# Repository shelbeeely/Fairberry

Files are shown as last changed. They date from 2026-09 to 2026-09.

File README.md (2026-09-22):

# Fairberry (e-ink fork)

This is a personal fork of [Dakkaron/Fairberry](https://github.com/Dakkaron/Fairberry), which adds a detachable BlackBerry Q10 keyboard to phones, physically clamped on and wired over USB. If you want that original phone-focused project, go there instead — this fork has moved away from it.

**The direction here now: a standalone, battery-powered BlackBerry-style device -- Q10 keyboard, a five-way trackball, a mic and speaker, microSD storage -- that pairs *wirelessly* with the [Xteink X4](https://www.xteink.com/products/xteink-x4) (or any BLE HID host) instead of physically attaching to it.** No separate battery / host-powered-only was the original project's whole philosophy; this fork has deliberately dropped that in favor of its own LiPo battery and its own enclosure, built primarily for e-ink devices running the [Free Ink SDK](https://freeink.org/) but not exclusive to them -- anything that speaks BLE HID keyboard is a valid target.

See [Hardware_Standalone_Smart_Keyboard.md](Documentation/Hardware_Standalone_Smart_Keyboard.md) for the current primary build. Two earlier, simpler stages are still in the repo and still valid if you want something less involved:
1. [Hardware_Fairberry_Mainboard.md](Documentation/Hardware_Fairberry_Mainboard.md) -- the original USB/BLE keyboard-only mainboard.
2. [Hardware_ESP32_Trackball_Mainboard.md](Documentation/Hardware_ESP32_Trackball_Mainboard.md) -- adds the trackball, still host-powered, classic ESP32.

The standalone smart keyboard supersedes both for pairing with the X4 specifically, but they're simpler builds if you don't want the battery/mic/speaker/SD/WiFi scope.

## Writer deck: four components, one repo

The keyboard alone is one half of the picture. Combined with an X4 running a FreeInk-SDK writer app, this becomes a full distraction-free writing device -- a "writer deck," in the vein of a Freewrite or AlphaSmart, built from this project's own parts. Four separate-but-interlinked pieces, all in this repo:

| Component | Directory | What it is |
|---|---|---|
| Keyboard firmware | [`BBQ10/`](BBQ10) | The physical keyboard + trackball + voice typing, BLE HID |
| X4 firmware | [`X4Firmware/`](X4Firmware) | The writer app (library + editor screens) running on the X4 |
| Hardware | [`KiCad/`](KiCad), [`Case/`](Case) | PCB design, 3D-printable case |
| Web GUI | [`WebGUI/`](WebGUI) | The keyboard-hosted local browser dashboard (implementation lives in `BBQ10/web_server.h`) |

Start with [Hardware_X4_Writer_Deck.md](Documentation/Hardware_X4_Writer_Deck.md) for how the pieces fit together -- it's also the most honestly unproven part of this repo (see its Status section: I read FreeInk SDK's docs site, but never had the actual SDK source or hardware in front of me to compile/test against, unlike the keyboard firmware).

## Status / known limitation

Good news on the software side: FreeInk SDK has a purpose-built BLE keyboard host — [`BleKeyboardHost`](https://freeink.org/docs/lib-ble) (the `lib-ble` library). Per its docs, it's a real BLE HID **host** (central role) that explicitly supports "keyboards, page turners, remote buttons and similar devices that expose the HID service" — not just page-turner remotes as I originally assumed here. It works on both ESP32-C3 and ESP32-S3 (BLE only, no Bluetooth Classic), which covers the plain X4 (C3) as well as the X4 Classic/Pro (S3). Pairing defaults to "Just Works" (no passkey needed), which is what a keyboard-only peripheral like Fairberry's `BOARD_TYPE ESP32` needs.

The catch: it's an **opt-in capability**, gated behind the `FREEINK_CAP_BLE_HID_HOST` build flag (off by default) plus adding the NimBLE stack as a dependency. So the real question isn't "does the ecosystem support external keyboards" (it does) — it's "does the specific firmware image flashed on your X4 have that flag turned on." Stock/vendor Xteink firmware almost certainly doesn't.

Checked directly against [freeink-sdk's `platformio.sample.ini`](https://github.com/Free-Ink/freeink-sdk/blob/main/platformio.sample.ini): the stock `[env:xteink_x4]` build env is just

```ini
[env:xteink_x4]
extends = base
board = esp32-c3-devkitm-1
build_flags =
  ${base.build_flags}
  -DFREEINK_DEVICE_X4=1
```

— no BLE HID host flag. Building a FreeInk-SDK firmware for the X4 that can actually pair with a Fairberry keyboard means adding, at minimum:

```ini
build_flags =
  ${base.build_flags}
  -DFREEINK_DEVICE_X4=1
  -DFREEINK_CAP_BLE_HID_HOST=1
lib_deps =
  ${base.lib_deps}
  h2zero/NimBLE-Arduino@^2.3.8
```

to your own build, then flashing that instead of whatever firmware is on the device now.

I have **not yet confirmed** this end-to-end against a physical X4 — that's the next step. I also haven't found documented USB HID host support in FreeInk SDK for any target, so the USB-attached Fairberry board types (`FAIRBERRY_V0_3_0`, `ARDUINO`) are more speculative than the BLE path right now; BLE (`BOARD_TYPE ESP32`) is the one with an actual matching host-side API to target.

## What can you expect?

Everything from the upstream project still applies at the electronics level: same BBQ10 keyboard, same mainboard, same firmware, same key combos (cursor mode, sticky modifiers, dead keys, backlight controls — see [UX_Shortcuts_and_Apps.md](Documentation/UX_Shortcuts_and_Apps.md)). What's changing here is the case/mount and the target device.

Demo video of the original phone version: Demo video showing the functionality of the Fairberry keyboard (https://www.youtube.com/watch?v=iDb8_ld9gOQ)

## How to build it?

**Standalone smart keyboard (primary build)**: `BOARD_TYPE FAIRBERRY_ESP32S3_SMART` on an ESP32-S3. See [Hardware_Standalone_Smart_Keyboard.md](Documentation/Hardware_Standalone_Smart_Keyboard.md) for the pin plan, BOM (mic, speaker, microSD, LiPo + charger), firmware, and key combo table. Opt-in flags in `configuration.h`: `TRACKBALL_ENABLED`, `AUDIO_ENABLED` (local recording/playback, fully offline), `WIFI_TRANSCRIPTION_ENABLED` (batch-syncs recordings to the OpenAI Whisper API), `TRANSFER_MODE_ENABLED` (local no-cloud web dashboard for browsing/downloading notes over LAN), `VOICE_TYPING_ENABLED` (immediate dictate -> hear it read back via TTS to verify -> Enter to send, like a phone's voice-to-text keyboard). The last three need `BBQ10/secrets.h` -- copy `secrets.h.example`. No enclosure design yet -- see that doc's Enclosure section for why. **None of this is validated against real hardware.**

**Simpler builds**, if you don't want the battery/audio/WiFi scope:
- [Custom mainboard](Documentation/Hardware_Fairberry_Mainboard.md) — `BOARD_TYPE FAIRBERRY_V0_3_0` (USB) or `BOARD_TYPE ESP32` (BLE), keyboard only.
- [+ trackball](Documentation/Hardware_ESP32_Trackball_Mainboard.md) — same `BOARD_TYPE ESP32`, adds `TRACKBALL_ENABLED`.
- [Old Arduino-based hardware](Documentation/Hardware_Arduinobased.md) also still works.

For these simpler, host-attached builds only (not the standalone smart keyboard, which has no case yet), there's a case preset: [Xteink X4 preset](Case/Generator/presets/XteinkX4.scad), built from width/thickness measured off a community-made, to-scale device model ([Zorian22's "Xteink X4 device model" on Thingiverse](https://www.thingiverse.com/thing:7287950), 114.2 x 69.2 x 6.2mm) rather than just the rounded marketing spec — better, but still not a full match to the real device shape. The preset file has step-by-step instructions for swapping in that actual dummy model file for a proper fit instead of the parametric approximation; I couldn't fetch it automatically since Thingiverse's terms block bots, so that step needs a normal browser download on your end. Print a bottom-only test fit before committing to a full case either way. The original phone presets (Fairphone 4, Samsung Galaxy A54) are still in the repo under `Case/Generator/presets/` for reference.

**Writer deck combined case**: [Case/WriterDeck/](Case/WriterDeck) -- a single clamshell enclosing both the keyboard and the X4 as one physical device, reusing a real interlocking hinge mechanism extracted from a user-provided reference model rather than designed from scratch. First-draft OpenSCAD, not print-tested -- see that directory's README for exactly what's confirmed-real (the hinge geometry, the keyboard module dimensions) versus still a placeholder (tray cavity depth, trackball position).

## How to use it?

[Key combinations and apps](Documentation/UX_Shortcuts_and_Apps.md)

## License

Same as upstream: [Attribution-NonCommercial-ShareAlike 4.0 International](https://creativecommons.org/licenses/by-nc-sa/4.0/) for the firmware and case files (see individual file headers), original work © Dakkaron.

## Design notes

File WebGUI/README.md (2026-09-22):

# Web GUI

The fourth component: a local browser dashboard for browsing/downloading voice notes and transcripts, served directly by the keyboard's own firmware over WiFi (no cloud, no separate server to run).

**The implementation lives in `../BBQ10/web_server.h`, not in this directory** -- it has to be compiled into the keyboard firmware to be served by it (the ESP32 *is* the web server), so it can't be a truly separate deployable app the way this directory's name might suggest. This README exists to document it as its own logical component per the repo's four-part split (keyboard firmware / X4 firmware / hardware / web GUI), and as the place to grow it if it outgrows a single header file.

See [Hardware_Standalone_Smart_Keyboard.md's transfer mode section](../Documentation/Hardware_Standalone_Smart_Keyboard.md#local-transfer-mode-no-cloud) for what it does, how to enable it (`TRANSFER_MODE_ENABLED`), and its known gaps (no tag filtering, no HTTP Range support for audio scrubbing).

## How it interlinks with the other three components

- **Keyboard firmware** (`../BBQ10`): hosts this. `SYM + T` toggles it on/off.
- **X4 firmware** (`../X4Firmware`): not directly connected to this -- the dashboard is reached from any browser on the same WiFi network (a phone, a laptop), not through the X4. Since the keyboard has no screen of its own, activating it types the dashboard's URL as keystrokes into whatever's focused on the paired host (see `../BBQ10/web_server.h`), which in the writer-deck setup would typically be the X4's editor.
- **Hardware** (`../KiCad`, `../Case`): no direct relationship -- this is pure firmware/software.

## If this grows into something bigger

Right now the dashboard is a single generated HTML string in `web_server.h` -- fine for its current scope (a file list with download/stream links). If it grows into something with real interactivity (editing tags, renaming files, a nicer UI), the natural next step is extracting real `.html`/`.css`/`.js` files into this directory and either serving them from SD (simple, but uses SD card space and a file read per request) or embedding them into the firmware binary at build time (keeps them servable without SD access, but needs a build step to generate the embedded data). Neither is done yet -- not needed for the current feature set.

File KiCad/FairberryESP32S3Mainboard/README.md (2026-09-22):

# FairberryESP32S3Mainboard

KiCad 7 schematic for the standalone smart-keyboard mainboard (ESP32-S3-WROOM-1,
trackball, mic, speaker amp, microSD, LiPo charger). Pin assignments match
`BBQ10/boards.h`'s `FAIRBERRY_ESP32S3_SMART` board type exactly.

31 components, 44 verified nets (every net has 2+ pins, no dangling nets).
Connectivity uses net labels (`(label "NETNAME" ...)`) on short wire stubs at
each pin rather than routed point-to-point wires, which is standard KiCad
practice for pin-dense boards and keeps the sheet readable.

Schematic

This is the schematic only -- `FairberryESP32S3Mainboard.kicad_pcb` exists
(see PCB section below) but only has the netlist imported: footprints sit on
an unplaced grid with no board outline or routing yet. `FairberryESP32S3Mainboard.svg`
is exported straight from the `.kicad_sch` via `kicad-cli sch export svg`
(see the command below); if you change the schematic, regenerate it the
same way so the image doesn't go stale:

```sh
export KICAD7_SYMBOL_DIR=/usr/share/kicad/symbols
xvfb-run -a kicad-cli sch export svg FairberryESP32S3Mainboard.kicad_sch -o /tmp/out
cp /tmp/out/FairberryESP32S3Mainboard.svg FairberryESP32S3Mainboard.svg
```

## Module SKU: ESP32-S3-WROOM-1-N16R8

The schematic symbol (`RF_Module:ESP32-S3-WROOM-1`) is generic across every
WROOM-1 flash/PSRAM SKU — the pinout is identical. For the BOM, this board
specs the **-N16R8** variant (16MB flash, 8MB octal PSRAM) for headroom on
audio buffers, the web dashboard, and WiFi/TLS.

That choice has one real consequence: on any *octal*-PSRAM WROOM-1 SKU
(anything ending `R8` or `R16V`), GPIO35/36/37 are wired internally to the
in-package PSRAM and can't be used as GPIO — they simply don't work as
signal pins, even though the generic symbol still draws them. A cheaper
*quad*-PSRAM SKU (`R2`, e.g. -N16R2, 2MB PSRAM) wouldn't have this
restriction and would need no pin changes, at the cost of much less RAM.
Having picked -N16R8, mic I2S was moved off GPIO35-37 onto GPIO43/44
(silkscreened RXD0/TXD0, i.e. UART0 — free because this board's console
runs over native USB, not UART0) and GPIO46 (a strapping pin, safe here
since MIC_DIN is an input and the mic's output doesn't drive that pin
during a bootloader-mode reset). See the comment above
`MIC_I2S_WS_PIN` in `BBQ10/boards.h` for the full reasoning.

## Known simplifications (not yet fab-ready)

- **J6 (USB)**: a plain 4-pin header standing in for a real USB-C receptacle.
  No CC1/CC2 pull-down resistors are present, so USB-C power negotiation
  won't work as-is — replace with a real USB-C connector symbol/footprint
  (with CC resistors) before fabrication.
- **U3 (3.3V LDO)**: uses the generic `Regulator_Linear:MCP1700x-300xxTT`
  base symbol (the `extends`-based `-330` variant wasn't practical to
  reference programmatically); functionally equivalent, same pinout.
- **U6 (battery-low supervisor)**: uses the generic
  `Power_Supervisor:MCP100-270D` base symbol; the real BOM part is the
  -300 (3.0V threshold) variant, same pinout.
- **U4 (MAX98357A)**: footprint is the QFN package; double-check against
  the actual part you source (some breakout modules differ).

## Regenerating the schematic

The `.kicad_sch` file is generated, not hand-drawn, from `generator/*.py`
(pulls real symbol/pin data straight out of the installed `kicad-symbols`
library files, plus a hand-built symbol for the BBQ10 keyboard's Hirose
connector sourced from `KiCad/FairberryMainboard/library/Keyboard.lib`).
To regenerate after editing `generator/build_sch3.py` (component list /
net map):

```sh
cd KiCad/FairberryESP32S3Mainboard/generator
python3 build_sch4.py
```

This overwrites `../FairberryESP32S3Mainboard.kicad_sch` and prints every
net with its pin list, plus a warning for any single-pin (dangling) net.

## Generating the PCB

`kicad-cli`'s `pcb` subcommand only has `export` in KiCad 7 -- there's no
`pcb import-netlist`, and the GUI's "Update PCB from Schematic" dialog
isn't exposed to scripting either. `generator/build_pcb.py` does that step
directly against the `pcbnew` Python API instead: it loads each
component's real footprint (verifying every one exists on disk -- one
placeholder footprint name and one wrong library path were caught and
fixed this way, see `build_sch3.py`'s `FP` dict comments), places them on
an unrouted grid, and wires every pad to its net by pad *number* (cross-checked
against each real `.kicad_mod` file, not assumed to equal the schematic
pin number sight unseen -- e.g. the microSD footprint's shield pin is 4
physical pads that all share pad number 9, matched by grouping pads by
number rather than taking the first hit).

```sh
cd KiCad/FairberryESP32S3Mainboard/generator
python3 build_pcb.py
```

This overwrites `../FairberryESP32S3Mainboard.kicad_pcb` and prints the
footprint/net counts. It needs `pcbnew` (KiCad's Python bindings,
`/usr/lib/python3/dist-packages/pcbnew.py` + `_pcbnew.so` on this
environment's install) importable from plain `python3` — no
`KICAD7_SYMBOL_DIR` or `xvfb` needed for this step, those only matter for
`kicad-cli`.

**Not done yet:** board outline, footprint placement (beyond "doesn't
overlap"), and routing. Placement/outline depend on the case's real
dimensions; routing is real layout work on top of this.

## Verifying with kicad-cli

`kicad-cli` (KiCad 7) needs `KICAD7_SYMBOL_DIR` set (the environment this was
built in didn't have it set by default) and a display, even for headless
export (it's a wx/GTK app under the hood) — use `xvfb-run` if there's no X
server:

```sh
export KICAD7_SYMBOL_DIR=/usr/share/kicad/symbols
cd KiCad/FairberryESP32S3Mainboard
xvfb-run -a kicad-cli sch export svg FairberryESP32S3Mainboard.kicad_sch -o /tmp/out
xvfb-run -a kicad-cli sch export netlist FairberryESP32S3Mainboard.kicad_sch -o /tmp/out.net
```

Then sanity-check the netlist: every net should have 2+ nodes except a
short, expected list of no-connects (unused ESP32-S3 strapping pins
IO0/IO3/IO45, the octal-PSRAM-reserved IO35/36/37 (see the Module SKU
section — RXD0/TXD0 aren't in this list anymore, they carry mic I2S now),
MAX98357A's NC pins, and J1's MIC pin from the keyboard connector, which
isn't used since a separate mic — U5 — is on this board).

To check the same thing on the PCB instead of the schematic (useful after
running `build_pcb.py`, to confirm every pad landed on the net it should
have):

```sh
python3 -c "
import pcbnew
board = pcbnew.LoadBoard('FairberryESP32S3Mainboard.kicad_pcb')
netpads = {}
for fp in board.GetFootprints():
    for pad in fp.Pads():
        netpads.setdefault(pad.GetNetname(), 0)
        netpads[pad.GetNetname()] += 1
single = [n for n, c in netpads.items() if c == 1 and n]
print('single-pad (dangling) nets:', single or 'none')
"
```

A PCB-only rendering (copper + silkscreen + outline, no schematic-style
labels) can be exported the same way as the schematic, except `-o` here
takes a file path directly rather than a directory when `--layers` is
given:

```sh
xvfb-run -a kicad-cli pcb export svg FairberryESP32S3Mainboard.kicad_pcb -o /tmp/out.svg --layers F.Cu,F.Silkscreen,Edge.Cuts
```

### Pitfalls hit building this (kept here so they don't get re-debugged)

- **kicad-cli segfaults** on any schematic referencing a real library
  symbol if `KICAD7_SYMBOL_DIR` is unset or there's no local/global
  `sym-lib-table` — but it *also* segfaults on a well-formed file if a
  symbol's cached name in `lib_symbols` doesn't exactly match its `lib_id`
  (e.g. a `Heater` block cached for something referenced as `Device:R`).
  Getting a clean `Failed to load schematic file` instead of a segfault
  means the structural error is at least being caught.
- **`(wire ...)` must not include a `(fill (type none))` clause** and
  should use `(type solid)`, not `(type default)` — copying the stroke
  syntax from a symbol's graphic *rectangle* onto a wire breaks loading.
- **Pin connection points must be exact, unrounded coordinates.** Snapping
  a computed pin position to the nearest 1.27mm grid before drawing its
  wire stub seems harmless but silently detaches the wire from the pin
  whenever the component's placement position isn't itself grid-aligned —
  the file still loads and renders fine, wires visually touch the pins,
  but `kicad-cli sch export netlist` shows almost everything as
  "unconnected". Always compute `component_position + pin_local_offset`
  with no rounding for the pin end of any wire.
- **A schematic's `Footprint` property string is never validated against
  real files.** The microSD footprint (`Connector_Card:Conn_01x08_MicroSD_Card`)
  was a guessed name that doesn't exist in KiCad's footprint library, and
  the custom keyboard connector's footprint was referenced under a made-up
  `Fairberry:` library instead of the real `Connectors_Hirose_extra:` one
  it actually lives in — both loaded fine as schematic text and only broke
  when `build_pcb.py` called `pcbnew.FootprintLoad()` on them and got
  `None`. Nothing catches a bad footprint string until PCB generation.
- **Footprint pads can outnumber symbol pins**, and pad *numbers* -- not
  symbol pin numbers assumed to carry over unchanged -- are what has to
  match. The microSD footprint has 4 physical shield pads that all share
  pad number 9, corresponding to the symbol's single SHIELD pin; grouping
  a footprint's pads by `GetNumber()` before assigning nets (rather than
  taking the first match, or assuming a 1:1 pad-to-pin count) is what
  catches this.

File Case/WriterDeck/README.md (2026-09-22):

# Writer deck combined case

A single clamshell enclosure holding both the [Fairberry keyboard](../../BBQ10) (keyboard + trackball + mic/speaker/battery board) and the Xteink X4 (screen board), as one physical device instead of two paired-over-BLE pieces. See [Documentation/Hardware_X4_Writer_Deck.md](../../Documentation/Hardware_X4_Writer_Deck.md) for the electronics/firmware side this wraps around.

**Status: first-draft OpenSCAD exists (`WriterDeck.scad`), built from a real reference model, not print-tested.** The user provided a reference case -- "XteinkX4FullCoverageFlipCase" (`reference/`, 3 STLs: `BOTTOM`, `TOP`, `HINGE` -- no author/license metadata embedded in the files, confirm the original source's license before redistributing publicly if it came from somewhere like Printables/MakerWorld/Thingiverse). Rather than design a hinge from scratch, this reuses that reference's actual hinge mechanism directly:

- **`BOTTOM.stl`** (27590 triangles, has real X4-specific port/button cutouts) is the X4 cradle. **Reused completely unmodified.**
- **`HINGE.stl`** (1432 triangles, a separate comb+pin bar spanning X 15.06-50.86mm) is the knuckle/pin piece that threads through both halves. **Reused completely unmodified.**
- **`TOP.stl`** (11760 triangles, much simpler than BOTTOM -- no device-specific geometry) was a plain flip-lid in the reference. Measured its two corner hinge-knuckle loops precisely (left loop: X[-2.9, 9.0] Y[105.1, 116.7] Z[6.0, 9.2]; right loop: X[59.7, 68.8], same Y/Z) and extract *just those* via `intersection()` in OpenSCAD -- the flat lid body itself is discarded and replaced with the keyboard tray. This means the knuckle-loop geometry is pixel-for-pixel identical to the tested reference, not a redrawn approximation.

Confirmed this way (not guessed): BOTTOM is the more geometrically complex piece (more than double TOP's triangle count) and sits at a lower Z range in the hinge region (Z up to 6.6) while TOP sits above it (Z 6.0-9.2) -- consistent with BOTTOM being a snug device cradle and TOP being a cover that closes over it, which is also why BOTTOM was the one worth keeping unmodified and TOP was the one safe to gut and repurpose.

## Decisions made so far

- **Portrait orientation -- reversed from an earlier landscape recommendation.** Before seeing the reference model, I'd recommended landscape (the X4's panel is natively 800x480, a landscape pixel buffer -- used as-sold in portrait for reading, the e-reader software rotates that framebuffer 90 degrees, and landscape avoids that rotation while matching Freewrite/Pomera/AlphaSmart's form language). The reference model changed that: it's built portrait (hinge along the X4's short ~70mm edge, footprint matching the X4 held as normally sold), with a real, evidently-tested interlocking hinge. Reusing that proven hinge outweighs the software-rotation nicety -- portrait rendering is already how the X4's stock reader software works, so it's a well-trodden path, not a risky one. Also, portrait keeps the case width close to the keyboard's own ~70mm width (no wasted bezel space), where landscape would have needed the case to be 114mm wide.
- **Clamshell, not rigid single-piece.** Folds closed like a small laptop. In the reference's own closed-position modeling (both halves share the same X-Y footprint, stacked in Z), the X4 half (`BOTTOM`) sits lower and the other half sits on top when closed -- doesn't dictate which one ends up "on the table" when opened, any more than it does on a real laptop.
- **Two independent electronics systems, one shared shell.** No PCB/firmware changes from this -- the X4 board and the Fairberry board each keep their own battery and BLE pairing exactly as already built. Purely a mechanical/enclosure question. No wires need to cross the hinge.
- **Reuse the reference hinge exactly, don't redesign it.** See the Status section above -- `BOTTOM` and `HINGE` reused unmodified, only `TOP`'s two corner knuckle-loops extracted and reused, its flat lid body replaced with the keyboard tray.

## What's still unverified in `WriterDeck.scad`

Everything the file's own comments flag as `UNVERIFIED`, specifically:

- **Keyboard tray cavity height/depth.** No PCB layout exists yet for `FAIRBERRY_ESP32S3_SMART` (see [Hardware_Standalone_Smart_Keyboard.md](../../Documentation/Hardware_Standalone_Smart_Keyboard.md)'s own "no enclosure yet" note) -- the electronics bay dimensions are a reasonable-guess placeholder, not fitted to anything.
- **Trackball/keyboard cutout exact positions.** Keyboard cutout uses the *real* measured dimensions of `Case/Generator/import/BBQ10KBD.stl` (66.6 x 36.1mm) -- that part's solid. Its position within the tray, and the trackball cutout's position/size (28x22mm from the trackball doc's BOM, not measured against a real trackball model), are first-guess placements reasoned from BlackBerry-style ergonomics (trackball near the hinge/screen edge), not fitted to real board geometry.
- **Wall thickness (2mm) and hinge alignment tolerance** -- not print-tested against either this design or even the reference case itself (which I've only analyzed geometrically, not printed).
- **Battery access** (charging/replacement) on both halves isn't addressed at all yet.

## Next step

Print a test fit of just the hinge region first (both halves, short in Y, just enough to include the knuckle loops + a few mm of tray) before committing to a full-size print -- same advice as everywhere else in this repo that carries an "unverified" tag. Then iterate on the tray cavity dimensions once there's a real PCB (or at least a breadboard mockup) to measure against.

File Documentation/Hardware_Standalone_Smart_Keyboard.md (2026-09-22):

# Standalone smart keyboard: ESP32-S3 + trackball + voice notes

This supersedes the direction in [Hardware_ESP32_Trackball_Mainboard.md](Hardware_ESP32_Trackball_Mainboard.md) for a bigger pivot: instead of a host-powered accessory, this is a standalone, battery-powered device with its own enclosure that **pairs wirelessly** with the Xteink X4 (or another BLE HID host) rather than physically attaching to it. It keeps the BBQ10 keyboard and the ICSH044A trackball from that earlier doc, and adds a microphone, speaker, microSD storage, a LiPo battery, and Wi-Fi-based voice transcription via the OpenAI Whisper API.

**Status: architecture + firmware, not a fabricated/tested board**, same caveat as the trackball doc before it. Nothing here has touched real hardware. The pin table especially should be treated as a reasoned starting point, not a verified-correct final assignment -- see the note in that section.

## Why ESP32-S3 (changed from the trackball doc's classic ESP32)

The trackball-only doc deliberately stayed on classic ESP32 to avoid an unnecessary chip port. That reasoning doesn't hold anymore:

- **GPIO budget**: mic + speaker (I2S) + SD (SPI) + battery monitoring pushes pin count well past what's comfortable on classic ESP32, especially once the trackball's 4 direction lines are added back in. S3 has significantly more usable GPIO.
- **No more input-only-pin problem**: classic ESP32's GPIO 34/35/36/39 have no internal pull-up/down hardware, which is why the trackball doc needed external pull-up resistors and a workaround pin assignment. S3's GPIO 0-21 are all normal bidirectional pins with full pull capability, which simplifies the trackball wiring too.
- **RAM/PSRAM**: buffering audio for WAV writes and HTTPS JSON responses at the same time wants more RAM than classic ESP32 has to spare. This board specs the ESP32-S3-WROOM-1-N16R8 SKU (8MB octal PSRAM) for that headroom -- see the Pin plan section for the GPIO tradeoff that choice costs.
- **This is also just the chip the earlier "smart ML keyboard" conversation was pointing at** (TFLite Micro / vector instructions for things like trackball gesture recognition), so this consolidates onto one chip instead of maintaining two board types for related features.

This does mean re-deriving parts of the firmware that assumed classic ESP32 (see Firmware section) rather than reusing the trackball board type's `BOARD_TYPE == ESP32` code paths directly.

## Power: LiPo battery, not host-powered

This is a real change of philosophy from the rest of this repo (the USB/Arduino board types are explicitly host-powered with no battery). Get this part right -- LiPo mishandling is a fire risk, not just a design nitpick:

- **Use a protected cell.** A LiPo pouch cell with a built-in protection PCB (over-charge/over-discharge/over-current cutoff) is non-negotiable, not a nice-to-have.
- **Charge IC**: a standard linear charger like the MCP73831 (single-cell, sets charge current via one resistor, JST-PH battery connector) is the well-trodden, low-risk choice here -- it's what the overwhelming majority of small LiPo hobby projects use. Add its STAT pin straight to an LED + resistor for a charge-status indicator; that doesn't need to cost an MCU pin.
- **Fuel gauge (recommended)**: a coulomb-counting gauge like the MAX17048 gives an actual battery-percentage reading over I2C instead of a rough voltage-divider guess, and it's cheap. If skipping it to save cost/pins, fall back to a simple ADC voltage divider on the battery line (~2:1 divider into an ADC-capable GPIO, with the usual caveat that LiPo voltage-to-charge-% curves are nonlinear and this reading will be a rough estimate at best, especially under load).
- **Load switch / deep sleep**: route mic, speaker amp, and SD card power through a MOSFET load switch gated by the MCU, so they can be fully powered down (not just idled) between uses -- this is where the actual battery-life win comes from, more than any peripheral-level low-power mode.
- **Cell size**: pick based on the enclosure size once that's designed; a 500-1000mAh pouch cell is a reasonable starting range for a pocket-sized device with WiFi used briefly once or twice a day, not continuously.

## New peripherals

| Peripheral | Suggested part | Interface |
|---|---|---|
| Microphone | ICS-43434 (I2S MEMS mic; same category of part as the INMP441 this doc originally specified, switched to one with a real KiCad symbol available) | I2S, digital output avoids analog noise pickup |
| Speaker amp | MAX98357A (I2S Class-D amp) + small 8Ω speaker | I2S |
| Storage | microSD (SDMMC 1-bit mode, not SPI -- see Pin plan below for why) | SDMMC |
| Fuel gauge | Not included in this revision -- no spare pin for it, see the Pin plan's battery-monitoring note | -- |
| Charger | MCP73831 | Standalone, JST-PH battery connector |

## Pin plan

Mainboard schematic

*Full schematic (30 components, 44 verified nets) — see [`KiCad/FairberryESP32S3Mainboard/`](../KiCad/FairberryESP32S3Mainboard) for the source `.kicad_sch`, the generator scripts that build it, and how to regenerate/re-verify it with `kicad-cli`. Schematic only — no PCB layout yet.*

**Corrected and verified against the real ESP32-S3-WROOM-1 KiCad symbol** (`RF_Module:ESP32-S3-WROOM-1`, used in [`KiCad/FairberryESP32S3Mainboard/`](../KiCad/FairberryESP32S3Mainboard)), not against a guess about which GPIOs a generic "ESP32-S3 module" exposes. An earlier version of this table assumed GPIO22-25 and GPIO33-34 were available (true on the classic ESP32, not true on this module -- they're used internally for flash/PSRAM and aren't brought out to pins at all). The module exposes **GPIO 0-21 and 35-48 as general IO, plus separately-named RXD0/TXD0 pins (this module's real UART0, electrically GPIO44/43)** -- 34 general IO pins, 28 usable after excluding strapping pins (0/3/45/46) and reserving 19/20 for native USB.

**Module SKU: ESP32-S3-WROOM-1-N16R8** (16MB flash, 8MB octal PSRAM), picked for headroom on audio buffers, the web dashboard, and WiFi/TLS rather than leaving RAM unspecified. This has one real consequence for the pin table below: on any *octal*-PSRAM WROOM-1 SKU (`R8`/`R16V`), GPIO35/36/37 are wired internally to the in-package PSRAM and cannot be used as GPIO -- they simply don't work as signal pins on this SKU, even though the generic schematic symbol still draws them as ordinary pins. (A cheaper quad-PSRAM SKU like `-N16R2`, 2MB PSRAM, wouldn't have this restriction and would need no pin changes -- it's a real tradeoff, not a strictly-better option.) Mic I2S is moved off GPIO35-37 onto GPIO43/44 (the RXD0/TXD0 pins, i.e. UART0) and GPIO46 as a result -- see below.

28 pins needed, 28 available -- **this fits with zero spare margin**, which forced three real design changes from the original plan:

- **SD moved from 4-pin SPI to 3-pin SDMMC** (the ESP32-S3's native 1-bit SDMMC peripheral -- `storage.h` uses `SD_MMC.h`, not `SD.h`+`SPI.h`).
- **RGB trackball LEDs cut from this revision entirely.** There wasn't a pin left for them after fixing the GPIO22-25/33-34 mistake. `TRACKBALL_LED_ENABLED` isn't wired up for this board type -- a future revision would need an I2C GPIO expander or a module with more exposed GPIO.
- **Mic I2S moved onto UART0 + one strapping pin** (see the SKU note above), which means the serial console/flashing path for this board is native USB (GPIO19/20), not UART0 -- set `ARDUINO_USB_CDC_ON_BOOT=1` (or the ESP-IDF equivalent) rather than relying on RXD0/TXD0 for `Serial`.

| Function | Pins | Notes |
|---|---|---|
| Keyboard rows (7) | 1,2,4,5,6,7,8 | |
| Keyboard cols (5) | 9,10,11,12,13 | |
| Keyboard backlight | 14 | |
| Trackball UP/DOWN/LEFT/RIGHT | 15,16,17,18 | All normal GPIOs on S3 -- internal pull-ups usable, but keep external pull-ups too per the trackball doc's polarity caveat |
| Trackball BTN | 48 | Not RTC-capable, so it can't double as a deep-sleep wake source the way an earlier draft of this table assumed -- see boards.h. Deep-sleep wake is open follow-up work. |
| Battery low-battery flag | 21 | **Digital flag, not an ADC voltage reading** -- every ADC-capable pin (GPIO1-10 and 11-20) is otherwise committed by the time the keyboard matrix, trackball, and USB reservation are accounted for. A real capability reduction from "know the battery percentage": see boards.h's `BATTERY_LOW_PIN` comment for the reasoning and the upgrade path (an I2C fuel gauge, which doesn't need an ADC-capable pin, but does need a pin this board doesn't currently have spare). |
| Mic I2S (WS/BCLK/DIN) | 43,44,46 | GPIO43/44 are the module's UART0 pins (RXD0/TXD0), free because this board's console runs over native USB instead. GPIO46 is a strapping pin, safe here because MIC_DIN is an input and the mic's output doesn't drive it during a bootloader-mode reset. **Not GPIO35-37** -- those are unusable on the -N16R8 (octal PSRAM) SKU this board specs, see above. |
| Speaker I2S (WS/BCLK/DOUT) | 38,39,40 | Separate I2S port from the mic rather than a shared-clock setup, simpler to get right |
| SD SDMMC (CLK/CMD/D0) | 41,42,47 | 1-bit mode |

No spare pins remain for anything not already listed here -- a status LED, a dedicated power button, a fuel gauge, anything else would need to displace something above rather than just being added.

If you're hand-wiring a prototype rather than using the KiCad board, get the mic+speaker+SD+keyboard+trackball working incrementally on a breadboard, same as any board bring-up.

## Firmware

New modules, all opt-in and independent of the existing keyboard/trackball code paths:

- `BBQ10/storage.h` -- SD card init and file helpers.
- `BBQ10/audio.h` -- I2S mic capture to WAV on SD, I2S speaker playback, confirmation tones.
- `BBQ10/whisper_sync.h` -- Wi-Fi connection, SNTP time, scanning SD for un-transcribed recordings, uploading to the OpenAI Whisper API, writing the resulting `.txt` next to the `.wav`. Manual trigger (a key combo) and a once-daily scheduled sync.

Enabled via `WIFI_TRANSCRIPTION_ENABLED` in `configuration.h`. WiFi credentials and the OpenAI API key live in `BBQ10/secrets.h`, which is gitignored -- copy `BBQ10/secrets.h.example` and fill in your own values, never commit real credentials.

Required additional Arduino library: **ArduinoJson** (for parsing the Whisper API response), on top of the libraries already listed in [Hardware_Fairberry_Mainboard.md](Hardware_Fairberry_Mainboard.md).

### What this does and doesn't do

- Records audio locally to SD as WAV. This part works fully offline.
- Playback of stored recordings and short confirmation tones, also fully offline.
- Transcription requires Wi-Fi and an OpenAI API key, and happens only when a sync runs (manual trigger or once daily) -- it is not real-time, and it depends on an external paid API. Recordings made with no Wi-Fi in range just wait on the SD card until the next successful sync.
- There's no on-device speech recognition of any kind here -- see the earlier conversation in this repo's history for why (a real ASR model doesn't fit in a microcontroller's RAM budget). If you want offline transcription, that's a fundamentally different, much heavier approach (e.g. relaying audio to a more powerful paired host), not something this firmware attempts.

### Local transfer mode (no cloud)

Separate from Whisper sync, `TRANSFER_MODE_ENABLED` adds a local-only web dashboard for browsing and downloading recordings/transcripts over the LAN -- no OpenAI account needed for this one, just WiFi credentials. Toggle with **SYM + T**. `BBQ10/web_server.h` runs a plain HTTP server (`WebServer.h`, built into the ESP32 Arduino core, no extra library needed) listing `/recordings`, with download/stream links for each `.wav` and its `.txt` if one exists.

Since this device has no screen, there's no way to display its own IP address -- on activation it instead **types the local URL as keystrokes** into whatever's currently focused on the paired host, the same BLE HID path used for normal typing. Focus a text field on the X4 (or wherever) before toggling transfer mode on if you want to actually capture the URL; otherwise those keystrokes go wherever the host happens to be focused.

Not implemented: tag filtering (there's no tagging mechanism anywhere in this firmware yet -- recordings are just numbered), and HTTP Range requests aren't specifically handled, so audio scrubbing in a browser's `<audio>` player may or may not work depending on how your browser's player handles a non-seekable stream.

If both `WIFI_TRANSCRIPTION_ENABLED` and `TRANSFER_MODE_ENABLED` are on at once: a scheduled Whisper sync checks whether transfer mode is currently active before disconnecting WiFi at the end of its run, so it won't cut off an in-progress browsing session. They otherwise operate independently.

### Voice typing (record, verify by ear, then send)

A third, different mode from the two above: `VOICE_TYPING_ENABLED` gives you an immediate dictate-and-verify loop, closer to a phone's voice-to-text keyboard than to a note-recorder. **SYM + V** starts recording; pressing it again stops and immediately (not batched, not waiting for a daily sync) uploads the clip to Whisper, then sends the returned text to the OpenAI TTS API (`BBQ10/tts.h`, `/v1/audio/speech`) and plays the reply back through the speaker so you can hear whether it transcribed you correctly. After playback, **Enter** confirms and types the text into the host (`BBQ10/keystroke_util.h`'s `typeString()`, the same keystroke path used everywhere else); **Backspace** discards it; a 15-second timeout auto-discards if you walk away.

This is genuinely different from the batch sync -- that one is for a longer recording you're fine waiting on, this one is for a sentence or two you want to send right now, with a chance to catch a bad transcription before it goes out. It reuses `whisperTranscribeToString()` from `whisper_sync.h` (refactored to return text directly rather than only writing to a `.txt` file, so both modes share the same upload code).

**This flow runs blocking, synchronously**, start to finish -- WiFi connect, the Whisper round-trip, the TTS round-trip, playback, and waiting for your confirm keypress all happen with the keyboard/trackball not responding to anything else. Expect a real pause (WiFi connect alone can take several seconds) between stopping the recording and hearing it read back. Making this non-blocking would mean a proper async state machine spanning multiple network round-trips, which is a meaningfully bigger undertaking than this pass -- noted as a known limitation, not attempted here.

Recording for this mode reuses the same underlying `audioStartRecording()`/`audioRecordingActive` state as the batch-record combo (SYM + Backspace) -- `audioStartRecording()` now refuses to start a second recording while one's already active (from either combo), rather than silently corrupting/orphaning whichever one was already running, and both combos play a low failure beep if that happens.

## Key combos on this board (beyond the base keyboard ones in [UX_Shortcuts_and_Apps.md](UX_Shortcuts_and_Apps.md))

| Combo | Action | Requires |
|---|---|---|
| SYM + Backspace | Start/stop voice recording (saved for later batch transcription) | `AUDIO_ENABLED` |
| Hold trackball button 2s+ | Trigger a Whisper sync now | `WIFI_TRANSCRIPTION_ENABLED` |
| SYM + T | Toggle local transfer-mode web dashboard | `TRANSFER_MODE_ENABLED` |
| SYM + V | Start/stop voice typing (immediate transcribe + TTS verify + Enter to send) | `VOICE_TYPING_ENABLED` |
| Enter / Backspace | Confirm / discard, only while voice typing is waiting on you after playback | `VOICE_TYPING_ENABLED` |

## Enclosure

Not designed yet. The brief (screwless snap-fit two-half case, internal alignment pins for the board and buttons, rounded edges) is a reasonable, standard approach for a small battery-powered gadget, but the actual dimensions depend on the final PCB size and battery footprint, which don't exist yet -- there's no board layout to design a case around. This is real follow-up work once the electronics are prototyped on a breadboard/perfboard and a rough size is known, not something to draw blind.

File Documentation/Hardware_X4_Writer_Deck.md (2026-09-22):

# Writer deck: Fairberry keyboard + X4 running FreeInk SDK

This ties together everything else in this repo into one system: the [standalone smart keyboard](Hardware_Standalone_Smart_Keyboard.md) as the physical input device, and a FreeInk-SDK-based writer app running on an Xteink X4 as the screen/storage/editor -- a distraction-free writing device in the vein of a Freewrite or AlphaSmart, but built from this project's own parts.

**Status: the least proven part of this whole repo.** Everything about the keyboard side (BLE, trackball, voice typing) is firmware I could reason through carefully. The X4 side is different: I read FreeInk SDK's public docs site but never had the actual SDK source, a compiler, or hardware in front of me. `X4Firmware/src/main.cpp` is built against the *documented* API (confirmed: `EInkDisplay`, `BoardConfig`, `SDCardManager`, `BleKeyboardHost`/`BleHid`, and critically FreeInkUI's `textArea` component, which is described almost exactly as what a text editor needs) but several exact field/method names are my best reconstruction from prose docs, not verified against headers -- each is marked `// VERIFY:` in the source. Expect to fix compile errors against your actual `freeink-sdk` checkout, not just flash and go.

## Architecture

Two independent pieces of firmware, paired over BLE:

1. **Keyboard** (`../BBQ10`, `BOARD_TYPE FAIRBERRY_ESP32S3_SMART`) -- physical typing, trackball, mic/voice typing, all already built. It doesn't know or care that the host is running FreeInk SDK specifically; it's a generic BLE HID keyboard.
2. **X4 firmware** (`../X4Firmware`, this doc) -- a FreeInk SDK application that acts as a BLE HID **host** and renders a writer app: a library screen (browse/create documents on the X4's SD card) and an editor screen (`textArea` widget, autosaved).

They're linked at the protocol level (BLE HID) and at the build-flag level: the X4 firmware needs `FREEINK_CAP_BLE_HID_HOST=1` and the NimBLE dependency enabled, exactly as documented in the [main README's Status section](../README.md#status--known-limitation) and reproduced in `X4Firmware/platformio.ini`.

They can also be physically joined into one device instead of two BLE-paired pieces -- see [Case/WriterDeck/](../Case/WriterDeck) for a combined clamshell case, built by reusing a real interlocking hinge mechanism from a user-provided reference model rather than designing one from scratch. Electronics stay independent (separate boards, separate batteries, still talking over BLE) -- it's purely a shared enclosure.

## Setup

1. Clone `shelbeeely/freeink-sdk` next to this repo (or adjust the path in `X4Firmware/platformio.ini`'s `lib_deps`).
2. `cd X4Firmware && pio run -e xteink_x4 -t upload` -- expect to need to fix the `VERIFY:` spots in `src/main.cpp` against your actual checkout first.
3. Build and flash the keyboard firmware per [Hardware_Standalone_Smart_Keyboard.md](Hardware_Standalone_Smart_Keyboard.md).
4. Pair them. Bluetooth pairing UX on the X4 side isn't implemented in this pass -- see Known Gaps.

## What's implemented in `X4Firmware/src/main.cpp`

- Library screen: lists `/documents` on the X4's SD card, `+ New draft` starts a blank numbered file.
- Editor screen: a `textArea`-based distraction-free editor. Typing on the Fairberry keyboard inserts/deletes text at the caret; Left/Right arrows move the caret; Escape saves and returns to the library.
- Autosave every 5 seconds while actively typing.
- A periodic full e-ink refresh every 40 edits to clear ghosting from repeated fast partial updates, rather than full-refreshing on every keystroke (which would be slow and flashy) or never (which would leave visible ghosting).

## Known gaps (not implemented, not guessed at)

- **Up/Down arrow line navigation.** Needs `textArea` to expose which visual line/column the caret is on after word-wrap, which wasn't in the docs I could read. Left/Right plus the editor's own scrolling covers basic editing for now.
- **BLE pairing flow on the X4 side.** `BleHid.begin()` starts the host role, but the actual "scan, show discovered devices, let the user pick and pair" UX isn't built -- lib-ble's docs describe `startScan()`/`device()`/`connect()`/`takePairingPasskey()` for this, but wiring it into an actual pairing screen wasn't attempted here (this needs its own UI, out of scope for this pass).
- **On-screen keyboard fallback.** FreeInkUI has `keyboard`/`qwertyKeyboard` components for text input without the physical keyboard connected -- not wired in, since the entire point of this device is typing on the physical Fairberry keyboard, but it's a reasonable addition later (e.g. renaming a file, entering WiFi credentials).
- **Large documents.** The document buffer is a single in-RAM `String`. Fine for typical short-form writing-deck use, not designed for book-length documents -- a chunked/streaming buffer would be a real rewrite of the editor, not attempted here.
- **Integration with the keyboard's own voice-typing/transfer-mode features.** Those exist entirely on the keyboard side and just inject keystrokes -- from the X4 app's perspective a voice-typed sentence arrives as ordinary keystrokes into whatever's focused (the editor, if that's what's open), no special handling needed or added.

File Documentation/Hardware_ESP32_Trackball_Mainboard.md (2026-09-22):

# ESP32 mainboard + trackball: design notes

This documents adding an ICSH044A (SparkFun BlackBerry Trackballer Breakout clone, COM-09320-style) five-way trackball to a BLE-first Fairberry keyboard, wired up alongside the existing BBQ10 keyboard matrix on `BOARD_TYPE ESP32`.

**Status: this is an architecture proposal and a working firmware implementation, not a fabricated or tested board.** There's no KiCad schematic/PCB for this yet -- I don't have a way to lay out and verify a PCB in this environment (no KiCad GUI, no way to run ERC/DRC, and definitely no way to test on real hardware), so producing one blind would risk handing you something that looks finished but silently doesn't work. What's real and done: the pin plan below, and the firmware in `BBQ10/trackball.h` (gated behind `TRACKBALL_ENABLED` in `configuration.h`, off by default). What's still open: turning this into an actual schematic/PCB, and validating any of it against hardware.

## Why keep the classic ESP32 (not C3/S3) for this

The existing `BOARD_TYPE ESP32` code already targets the classic ESP32 specifically (`esp_pm_config_esp32_t`, `esp_bt_sleep_enable()`, etc. are chip-specific API names that wouldn't compile as-is on C3/S3 without changes). Reusing it instead of jumping to C3/S3 avoids introducing an untested chip-porting problem on top of an already-not-fully-tested board type. It also has a real upside for "work with anything that supports the wireless protocols": classic ESP32 has both BLE and Bluetooth Classic radios, where C3/S3 are BLE-only -- more headroom for compatibility later, even though this firmware only uses BLE HID today via the `BleKeyboard` library. It also has more usable GPIO than C3, which matters below.

## Pin plan

Reuses the existing `BOARD_TYPE ESP32` keyboard matrix pins unchanged (`boards.h`):

| Function | Pins |
|---|---|
| Keyboard rows (7) | 27, 25, 32, 4, 0, 2, 22 |
| Keyboard cols (5) | 5, 23, 19, 18, 26 |
| Reset | 33 |

New/changed for the trackball:

| Function | Pin | Notes |
|---|---|---|
| Keyboard backlight | **13** (was 35) | The existing pin map had this on GPIO35, one of the ESP32's 4 input-only ADC pins (34/35/36/39) -- no output driver exists on those at all, so backlight PWM could never have worked there. Moved to a normal I/O pin; this also frees 35 for the trackball below. |
| Trackball UP | 34 | Input-only pin. **Needs an external pull-up resistor to 3.3V** (e.g. 10k) -- these pins have no internal pull-up/down hardware, and whether the ICSH044A clone board has its own onboard pull-ups wasn't reliably confirmed during research. Add the resistor regardless; redundant is harmless, missing is not. |
| Trackball DOWN | 36 | Same as above. Silkscreened `SVP`/`VP` or similar on some devkits -- check your board's labeling, it's the same physical GPIO36. |
| Trackball LEFT | 39 | Same as above. Sometimes silkscreened `SVN`/`VN`. |
| Trackball RIGHT | 35 | Same as above (this is the pin freed from the backlight fix). |
| Trackball BTN | 14 | Normal I/O pin, uses the ESP32's internal pull-up (`INPUT_PULLUP` in firmware) -- no external resistor needed. Only 4 input-only pins exist on this chip and all 4 went to the direction lines, so BTN landed on a regular pin instead. |
| Trackball LED RED | 16 | Optional, only wired if `TRACKBALL_LED_ENABLED` is set. |
| Trackball LED GRN | 17 | Optional. |
| Trackball LED BLU | 21 | Optional. |
| Trackball LED WHT | *(not wired)* | Skipped -- there wasn't a 5th free flexible pin in this map. Drive RED+GRN+BLU together for a white-ish approximation if you want that, or free up a pin (e.g. reclaim GPIO2 from the keyboard matrix and move that row elsewhere) if you specifically want the true white LED. |

Pins avoided deliberately: GPIO 6-11 (internal flash, unusable), GPIO 1/3 (UART0, used for programming/serial monitor), and the strapping pins 0/2/5/12/15 where avoidable (two of these, 0 and 2, were already in use by the keyboard matrix rows in the *existing* pin map, not something introduced here -- left as-is for continuity rather than reshuffling working pin assignments).

## Bill of materials (additions)

- ICSH044A / BlackBerry trackball breakout board (2.5-5.25V, ~28x22x8mm)
- 4x 10kΩ resistors (pull-ups for UP/DOWN/LEFT/RIGHT -- see the pin table)
- Current-limiting resistors for the RGB LEDs if `TRACKBALL_LED_ENABLED` and the breakout doesn't already have them on-board (unconfirmed either way -- check with a multimeter/datasheet before assuming, then use standard values for the LED's forward voltage at 3.3V logic, typically in the 220-470Ω range for small SMD LEDs)
- Wire for 7-11 signal connections (5 functional + up to 4 LED) plus VCC/GND, same idea as the existing BBQ10-to-mainboard wiring in [Hardware_Fairberry_Mainboard.md](Hardware_Fairberry_Mainboard.md)

## Firmware

See `BBQ10/trackball.h` for the implementation and `BBQ10/configuration.h` for the `TRACKBALL_ENABLED`/`TRACKBALL_LED_ENABLED`/`TRACKBALL_EDGES_PER_STEP`/`TRACKBALL_BTN_KEY` switches. Short version: movement is read as raw hall-sensor edges via interrupts (the direction pins' idle polarity wasn't consistently documented across sources, so this counts transitions rather than assuming a signal shape) and converted into arrow-key taps once enough edges accumulate on an axis; the center click sends Enter by default. This is a deliberately simple mapping (see the earlier discussion in this repo's history for why arrow keys instead of a real mouse HID report -- mainly that it stays inside the existing pure-keyboard-HID firmware instead of needing a new BLE HID report type).

## Physical mounting

Not designed yet. The module is roughly 28x22x8mm (LxWxH) -- whatever cutout/mount goes into the case needs a hole for the ball itself plus clearance for the board and its wiring. Given the BlackBerry Q10 keyboard this project is built around never had a trackball (Q10 used a capacitive touch strip below the keys, not a trackball -- the trackball was on older BlackBerry Bold/Curve models), there's no existing cavity to reuse; this needs a new cutout in whatever case design ends up being used. Worth deciding where before finalizing the X4 case work: e.g. above the keyboard near the screen, or integrated into the case sleeve area.

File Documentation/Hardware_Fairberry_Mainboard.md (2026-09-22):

# Connecting to a Free Ink SDK device (e.g. Xteink X4)

This fork targets e-ink readers instead of phones — see the [README](../README.md) for why, and for the current status of keyboard-host support on the Free Ink SDK side. In short: the mainboard doesn't change based on what it's plugged into, but which `BOARD_TYPE` you pick in `configuration.h` determines *how* it presents itself as a keyboard:

- `ESP32`: presents as a **Bluetooth LE HID** keyboard, no cable needed. This is the recommended path for Free Ink SDK devices — the SDK has an actual BLE HID host library for this, [`BleKeyboardHost`/`lib-ble`](https://freeink.org/docs/lib-ble), which explicitly supports external keyboards (not just page-turner remotes) on both ESP32-C3 and ESP32-S3. It's gated behind the `FREEINK_CAP_BLE_HID_HOST` build flag though, which is off by default — so the firmware actually flashed on your reader needs to have that capability turned on. See the README's Status section for where this stands.
- `FAIRBERRY_V0_3_0` (or another custom-mainboard version) / `ARDUINO`: presents as a standard **USB HID** keyboard over the OTG cable instead. Whether your reader accepts this depends on whether its firmware runs USB in host mode — I haven't found documented USB HID host support in Free Ink SDK for any target, so treat this path as more speculative than the BLE one.

Either way, the matrix-scanning and key-combo behavior described in [UX_Shortcuts_and_Apps.md](UX_Shortcuts_and_Apps.md) is identical regardless of the host device, since it all happens in the mainboard's own firmware before anything is sent out.

For the case, see the [Xteink X4 preset](../Case/Generator/presets/XteinkX4.scad) instead of the phone presets referenced later in this document — swap the `include` line in `Fairberry.scad` accordingly.

# Bill of Materials

- Blackberry Q10 replacement keyboard
- Assembled mainboard from JLCPCB
- Solderable USB 2.0 OTG connector (can be USB C, Micro USB or even Lightning)
- Thin wires to connect the USB board to the PCB (The thinner the better)
- 6 Pin headers
- USBASP Programmer
- Jumper wires

# Ordering from JLCPCB

## Downloads

First go to the release page (https://github.com/Dakkaron/Fairberry/releases) and locate the newest release.

Download gerber-*.zip, BOM.xlsx and CPL.xlsx.

## Order Hirose Keyboard Connector

JLCPCB does not usually stock the keyboard connector (Hirose BM14B(0.8)-24DS-0.4V(53)). To get them to include this part in the assembly, you first need to order the part in their part sourcing programme. To do so:

- Head to the part ordering page: https://jlcpcb.com/parts
- Log in to your JLCPCB account (create one if you don't have one)
- At the part ordering page, search for this part: HRS(Hirose) BM14B(0.8)-24DS-0.4V(53)
- There should be one result. Select it, choose an amount (2 or multiples of 5) and then press "Add to My Part Lib" and follow the order process
- Sourcing the components will take a few weeks
- Once they sourced the parts, they will refund you the difference between what you paid and what JLCPCB paid to the part seller, so it will likely be a bit cheaper than what you paid up front

## Order PCB

- Head to the JLCPCB PCB ordering page: https://cart.jlcpcb.com/quote?orderType=1&stencilLayer=2&stencilWidth=100&stencilLength=100&stencilCounts=5
- Upload the gerber-*.zip file. You can leave everything in the main box on default.
- Scroll down until you find "PCB Assembly" and activate that.
- Depending on how many parts you want to order, select 2 or 5 under "PCB Assembly". Ordering more parts will be cheaper per part. Please note, you will receive 5 boards regardless, but only the selected amount will be populated (will have components soldered to it).
- Press "Next".

## BOM and CPL

On the following page, upload the BOM.xmlx and the CPL.xmlx. On the dropdown on the bottom of the page select "Office Appliance and Accessories" -> "Keyboard".

Press "Next" again.

## Component list

You should now see a list of components. Verify that no errors (e.g. "Component out of stock") are displayed and all parts are selected. You should be able to take the Hirose connector from your part library.

Press "Next" again.

## Component placement

The next page shows a rendering of the component placement. Verify (multiple times) that the image looks exactly as the image below. Especially all the pink markings need to be exactly the same.

Component placement image

If one of the parts is rotated wrong (indicated by the pink markings being in the wrong location), select the component and use the "All Rotate Right/Left" buttons at the top to fix it.

If you are really sure it looks the same, press "Save to cart" and procede with ordering the PCB.

# Remaining Assembly

Solder the programming headers like in the picture below. These pin headers are only required for initial flashing, and can be desoldered afterwards, as they won't be needed anymore.

Placement of programming pin headers

Now take your USBASP and some jumper wires and connect the headers to the fitting pins on the programmer, following the images below. The pinout of the USBASP is shown here as viewed into the connector, with no cable plugged in.

Make sure you are using pinout for the right mainboard version.

## USBASP
USBASP pinout

## v0.1.1
![]()
Fairberry v0.1.1 pinout

## v0.2.0
Fairberry v0.2.0 pinout

## v0.3.0
Fairberry v0.3.0 pinout

Now solder the USB connector to the USB port on the Fairberry mainboard. Take care to get the pinout right and not cause any shorts.

Fairberry v0.1.1 with USB connector

# Flashing the firmware

## Flashing the bootloader

This step only needs to be done once. After you flashed the bootloader, you can update the firmware over the USB connector.

Download and install the [Arduino IDE](https://www.arduino.cc/en/software).

Open the Arduino IDE.

Connect the USBASP with the connected Fairberry Mainboard to a USB port of the computer.

WARNING: DO NOT PLUG THE USB CONNECTOR OF THE FAIRBERRY INTO THE PC, WHILE THE USBASP IS CONNECTED!

In the Arduino IDE, select "Tools" -> "Board" -> "Arduino AVR Boards" -> "Arduino Leonardo". Then select "Tools" -> "Burn Bootloader".

This will take a while. Wait until it finishes. If there are errors, check your solder joints and the wires connecting the Fairberry to the USBASP.

Once this is done, disconnect the Fairberry from the USBASP. You can now desolder the header pins.

## Flashing the firmware

Head to the [releases page](https://github.com/Dakkaron/Fairberry/releases), download and unzip the file BBQ10_Arduino_sources.zip.

Open the BBQ10.ino in the Arduino IDE.

In the Arduino IDE select "Tools" -> "Manage Libraries".

In the Library Manager, check that the following libraries are installed (and install them if they aren't):

- Keyboard, by Arduino, version 1.0.4 or newer
- LowPower_LowPowerLab, by LowPowerLab, version 2.2.0 or newer.

Now close the Library Manager.

Open the file configuration.h in the Arduino IDE.

Find this line

    #define BOARD_TYPE FAIRBERRY_V0_3_0

and adjust the board type to the version that you are using.

Make sure the USBASP is disconnected from the PC and the Fairberry Mainboard.

Connect the Fairberry Mainboard's USB connector to the PC.

Select "Sketch" -> "Upload" and wait for the upload to finish.

If you get an error, verify your soldering.

# Testing

Now you are basically done. To test the mainboard, connect the Blackberry Q10 keyboard to the connector and plug the whole thing into the USB port of your device (or, for `BOARD_TYPE ESP32`, pair it over Bluetooth). Open something where you can type and check if every key works as expected. If nothing types at all, that's the host-side keyboard support question from the top of this document, not a hardware fault — first confirm the device accepts input from *any* external USB/BLE HID keyboard before troubleshooting the Fairberry mainboard itself.

## Troubleshooting

If some keys work but others don't, some of the pins on the Hirose connector aren't soldered correctly. To figure out which ones, check out this [Column to row key matrix](https://github.com/arturo182/BBQ10KBD#columnrow-to-key-matrix).  With this you can figure out, which rows/colums have bad contacts.

Now look at this [breakout adapter](https://github.com/arturo182/bbq10kbd_breakout) and follow the traces from the defective row/column pin to the pin on the connector to figure out, which pin has a bad contact.

If you know which pin is at fault, try to carefully solder it on with a fine-tipped soldering iron.

## Generating the 3D-print file for the case

### Prerequisites
- Install [OpenSCAD](https://openscad.org/)
- Download and extract the Source Code zip file from [the newest release](https://github.com/Dakkaron/Fairberry/releases)
- Open `Fairberry-x.x.x/Case/Generator/Fairberry.scad` in OpenSCAD

### Customizing
- In the `Fairberry.scad` script, set the `SCREEN_PROTECTOR_HEIGHT` to the thickness of your screen protector. If you don't use one, set it to `0`.
- Set the `EXTRUSION_WIDTH` to the extrusion width of your 3D printer. For 0.4mm nozzles, it's usually 0.48. If you use a resin printer, leave it at 0.4.
- If you are using an Xteink X4, keep `include <presets/XteinkX4.scad>` uncommented (this is the default in this fork). Read the comment at the top of that file first — it's built from a community-measured device model rather than just the raw spec sheet, and includes steps for swapping in the actual dummy model for a better fit, but hasn't been validated against a physical unit. Treat the first print as a test fit.
- If you are using a Fairphone 4 or a Samsung Galaxy A54, comment out the active `include` line and uncomment the line fitting your phone instead. You can skip the rest of the customization.
- If you are using a different device, open up `Fairberry-x.x.x/Case/Generator/presets/Custom.scad` in OpenSCAD and customize the values in there to your liking. To preview the changes, save your changes in the `Custom.scad` and then open up `Fairberry.scad` in OpenSCAD, comment in its `include` line and comment out any other preset's, and press F5 to generate a preview.
- When using `Custom.scad`, it is recommended to find a dummy STL of your device. [Yeggi.com](https://www.yeggi.com/) and [Grabcad](https://grabcad.com/) are good sources for dummy models.

### Generating the file
- Once everything is customized to your liking, open `Fairberry.scad` and press F5 to generate a preview.
- Press F6 to render the file (this may take multiple minutes depending on your hardware).
- Press F7 and save the resulting STL file as `Fairberry.stl`.

## Printing the case

You need to print two files: The `Fairberry.stl` you generated in the last step and the `Fairberry-x.x.x/Case/Generator/USB_Clamp.stl`.

If you don't own a 3D printer, [JLCPCB](https://jlc3dp.com/3d-printing-quote) is a good place to start.

## Assembly

First secure the flex PCB of the keyboard with a bit of kepton tape. This is done to reduce the risk of ripping the flex PCB at the point where it enters the keyboard.

Kepton on flex PCB

Next put a small roll of Blu-Tack/Patafix onto the flex PCB and CAREFULLY bend it, like in the picture below. Warning, bending needs to be done carefully, otherwise it can break. Don't bend it more often than necessary. The roll of Blu-Tack/Patafix is there to cushion the bend a bit, so that it doesn't have as much strain on it.

Folding flex PCB

Optionally you can wrap the mainboard in kepton tape. This reduces the risk for shorts and keeps it clean from Blu-Tack/Patafix. Make sure to keep the keyboard connector free of kepton.

Mainboard wrapped in kepton

Put some thin blobs of Blu-Tack/Patafix onto the backside of the mainboard and plug the keyboard's flex PCB into the mainboard.

Patafix on mainboard

Carefully bend the Flex PCB into an S-shape under the mainboard and very carefully press the mainboard onto the keyboard, so that the Blu-Tack/Patafix can stick to the keyboard. Optionally, you can now also put a strip of kepton over the keyboard connector, to secure it to the mainboard.

Mainboard on keyboard

Put the M3 screws through the hole in the case and place the USB connector into the fitting hole.

Preparing USB connector

Put the M3 nuts into the holes in the USB clamp and screw it down. To help aligining the USB connector, place your device into the attachment and plug the USB connector into it, before screwing it down. This makes sure that the USB corrector is aligned correctly.
Also put a thin roll of Blu-Tack/Patafix on the top part of the area where the keyboard goes.

Preparing USB connector

Lastly, hook the bottom lip of the keyboard into the fitting hole in the case and carefully slide it in at an angle from the top. It might take a bit of careful force to put it in.

Fully assembled attachment

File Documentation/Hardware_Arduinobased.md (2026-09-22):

# This information is outdated. The newer hardware version can be found [here](https://github.com/Dakkaron/Fairberry/blob/main/Documentation/Hardware_Fairberry_Mainboard.md)

# Note (this fork)

This page still talks about attaching the keyboard to a phone, since it's kept largely as-is from upstream. Everything below applies the same way if you're building this for an e-ink device instead — see [Hardware_Fairberry_Mainboard.md](Hardware_Fairberry_Mainboard.md#connecting-to-a-free-ink-sdk-device-eg-xteink-x4) for the e-ink-specific notes (BLE vs. USB, host-support caveats, case preset).

## How is it working?

Underside of the electronics
Other angle of the underside of the electronics

There are five parts to the Fairberry keyboard:

- A BlackBerry Q10 replacement keyboard from Aliexpress (~�10-15 plus shipping)
- The BlackBerry Q10 Keyboard Breakout Board from here: https://github.com/arturo182/bbq10kbd_breakout
- An Arduino Pro Micro (Micro, not Mini! This is very important since the Pro Mini does not have USB interface that can be used to emulate a keyboard!)
- An USB C or Micro USB OTG breakout board or cable to connect to the phone
- The 3D printed case

> :warning: **Please read (and understand) the whole page before buying/building it!**

> :warning: **Messing this up can result in damage to your phone, your PC and/or the parts used in this build. If you are new to soldering, ask someone for help! I am not responsible for any damage that you do to your stuff! You are doing this at your own risk!**

### The BlackBerry Q10 Keyboard

This is just a regular keyboard for the BBQ10. You can either buy a replacement one from eBay or Aliexpress, or scavenge one off a BlackBerry Q10. Better get multiple ones, if shipping is slow. The flex PCB needs to be bent and can break in this process.

I decided to use the Q10's keyboard (and not, for example, the Key1/Key2 keyboard) since the Q10 keyboard is documented really nicely, and there are ready-made adapter designs, that I could use without having to design my own PCB.

I took the US Keyboard layout, since it was the easiest to get. If you get another keyboard layout you will need to adjust the keyboard mapping in the Arduino sketch.

### The BlackBerry Q10 Breakout Board

You can get the breakout board design files from here: https://github.com/arturo182/bbq10kbd_breakout

To get the board printed, you need to download the bbq10kbd_breakout repository files ("Code" -> "Download ZIP"). Next, put all files in the folder named "gerber" in a zip file and upload it here: https://jlcpcb.com/

The minimum order quantity at JLCPCB is 5. It is not a mistake to order more, this part is really tricky to solder. If you haven't soldered small SMD components before, you will need a few tries.

You also need to buy some Hirose BM14B(0.8)-24DS-0.4V(53) connectors. They are a bit hard to get. One place to get them from is https://www.mouser.at/ProductDetail/Hirose-Connector/BM14B08-24DS-04V53?qs=QRVci0nWsCaR3TeKMbLD%252Bw%3D%3D

Also here, get a few of them. You are going to need them.

Once you have those parts, the connector needs to be soldered to the board.

If you don't feel comfortable soldering something that tiny, go to your local phone/laptop repair shop. They usually have the equipment and skill to solder something like that for a few Euros.

If you've done that, that was the trickiest part.

Make sure you verify with a multimeter that all the conenctions are working and there are no shorts.

### The Arduino Pro Micro

Make sure you get an Arduino Pro Micro, and not the Pro Mini. The Pro Mini uses a different chip that doesn't natively support USB, and it will not work. To work, your Pro Micro should have an AtMega32u4 chip on it. It doesn't matter too much what kind of USB connector is on there, since we are going to remove that one anyways.

First, flash the BBQ10.ino sketch to your Arduino. For that, download the BBQ10 folder in this repository, download the Arduino IDE, and open the BBQ10.ino in the Arduino IDE.

Next, select "Tools" -> "Board" -> "Arduino Leonardo".
Now select "Tools" -> "Port" and note down all ports listed there (if there are any)
Then connect the Arduino to the PC using an USB cable, and recheck "Tools" -> "Port" for the new port that should have appeared. Select that port.
Now you can flash the sketch to the Arduino using "Sketch" -> "Upload".

You can now desolder the USB socket from the Arduino.

### The USB connector

Depending on your phone, get an USB C or Micro USB connector. You can either use OTG Breakout Boards (they give really good results, since they are very small) or USB 2.0 OTG cables (they are easier to find and easier to work with). What you choose is up to you.

If you got a cable, cut it about 5 cm from the connector. Strip about 2 cm of the outer plastic and shielding. Cut off any bare wires, so that there are only four cables left over. These should be red (5V), black (GND), green (Data-) and white (Data+). Strip the ends of the four cables and spread them apart. Make sure they don't touch. Now plug them into your phone and, using a multimeter in voltage mode, touch the red and black wires with the respective colored leads on the multimeter. Check that the multimeter displays 5V. If it doesn't, throw away the cable and get a new one. The reason is, that there are some extremely cheaply made USB C cables with wrong wireing. One of these cables might fry your keyboard and/or your phone. Make sure, you detach the cable from the phone when you are done. Shorting these cables while connected to your phone could also fry your phone.

### The Case

The cases are still work in progress.

The cases are plug-and-play, so you can easily replace the case at a later date, without having to change anything about the electronics.

Currently, there are two options: A bottom-only case (which is what is shown in the pictures above) and a full-body multimaterial case. For the multimaterial case you need a 3D printer capable of handling two different materials at the same time (e.g. by having two extruders). Also, the printer needs to be able to handle flexible materials.

The files for the cases are in the Cases-folder of this repository.

Print files with _PLA in the name in any hard plastic of your choice (PLA, PETG, ABS, ...). Any will work.

Print files with _TPU in the name in any flexible plastic of your choice (TPU, TPE). A bit harder might be better, but since I have only used one type of flexible filament (FlexiSmart), your milage may vary.

## Assembling all the parts

Assembly is a bit tricky. You will need either some double-sided tape or (what I used) some putty-like adhesive (e.g. Blu Tack or Patafix).

First, take the connector and the Arduino. Put them next to each other in the orientation shown on the following image:
Underside of the electronics

Using some thin enameled wire and solder, connect the pins like in the following table:

| Adapter | Arduino |
| --- | --- |
| Row 1 | 9 |
| Row 2 | 8 |
| Row 3 | 7 |
| Row 4 | 6 |
| Row 5 | 5 |
| Row 6 | 4 |
| Row 7 | A2 |
| Col 1 | A1 |
| Col 2 | A0 |
| Col 3 | 15 |
| Col 4 | 14 |
| Col 5 | 16 |
| GND | GND (I used the one next to Pin 2) |
| VCC | 10 (Used for the backlight) |

Do not connect the MIC or the unlabelled connector on the bottom right of the adapter.

The next step is to solder the USB connector to the Pro Micro. In the image you can see a small resistor at D+. You will not need that one. My Arduino had a defective resistor, and this is just overriding it. So, just ignore that resistor.
The following image shows where each of the USB connector's leads need to be soldered to:
Underside of the electronics

Now take the BlackBerry Q10 keyboard, and put it face down. Check the picture below for the finished assembly positions:

Next, take some Blu Tack/Pattafix/... and put a small bit on the keyboard, where the Arduino will come to rest. You will now have to bend the flex PCB in an S shape. Make sure you don't fold the PCB, since that might break it. Put some 1-2mm thick ropes of Blu Tack/Pattafix in the bends to make sure they don't fold. Connect the connector to your adapter. Make the S bend and stick the electronics down with a thin layer of Blu Tack/Pattafix.

The keyboard itself is now ready. You can connect it to a smartphone or keyboard and see if all keys work. You will need to set the keyboard layout on your device to standard (no layouts activated) if you get incorrect output. This is necessary, because Android 11 has a bug that distorts all other layouts if an accessibility service is activated.

If everything is working, it's now time to attach the keyboard to your phone.

Put a thin roll of Blu Tack/Pattafix at the top rim of the keyboard. This is used to stick the keyboard to the case. Slide the keyboard from the top into the recess at the bottom of the keyboard, and fold it down.

Your keyboard is now ready to be used!

## Android adjustments:

If the keyboard overlaps too much with your screen, install adb on your PC and enable Developer Options on your phone. Connect the phone to the PC and open a shell window (under Windows cmd, under Linux/MacOS use bash or whatever you have) and execute the following command:

```
adb shell wm size
```

This shows the current resolution of the smartphone. Now reduce the second number by doing this:

```
adb shell wm size 1080x2200
```

You will have to figure out what resolution you want to use, so just try out which values fit for you.
To reset it to default, execute this command:

```
adb shell wm size reset
```

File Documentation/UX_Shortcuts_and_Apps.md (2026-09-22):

# Which parts of this page apply to e-ink devices?

Everything the mainboard firmware does — cursor mode, sticky modifiers, dead keys, backlight brightness — happens before anything leaves the keyboard, so it applies the same way no matter what it's plugged into. That's the "Built-in key combinations" section below.

Everything below "Adding key combinations" is Android-specific (it relies on Android apps like Key Mapper and Automate, and on `adb`), and won't apply to a Free Ink SDK device. What key-remapping or shortcut options exist on the reader side is currently unknown/untested — if you figure something out for a Free Ink SDK device, that's worth documenting here or upstream in [freeink-sdk](https://github.com/Free-Ink/freeink-sdk).

# Keyboard layout on Android phones

The Fairberry requires you to set the layout to be set to "English (USA), international".

The reasons are
- It allows for accented letters that should cover many languages quite well.
- Some Android versions (at least up to Android 12) have a bug that the system forces this layout if you use accessibility services.

This section doesn't apply outside of Android — a Free Ink SDK device's keyboard layout handling (if any) hasn't been documented here yet.

# Built-in key combinations

These key combinations work out of the box and don't require any other apps.

- Both shifts at the same time: Enter cursor mode, where WASD are cursor keys and Q is ESC
- Both shifts when in cursor mode: Exit cursor mode
- The microphone key (same key as 0) is mapped to Ctrl
- For all modifier keys (Alt, Shift, Ctrl, Sym):
  - Hold while typing other keys: Modifier applies to all keys while held
  - Click the modifier once and let go: The next keystroke will be affected by the modifier
  - Click the modifier twice: This modifier is locked (like caps lock)
  - Click the modifier another time: This modifier is deactivated again (same as not pressed at all
  - Clicking a different modifier key will deactivate the first.
- Alt + U: Dead key ¨. For example: Alt + U followed by O results in ö
- Alt + I: Deat key ˆ
- Alt + S: ß
- Alt + C: ç
- All of these can be capitalized by pressing e.g. Alt + U followed by Shift + O.
- Sym + Alt: Tab
- Ctrl + Sym: Increase keyboad backlight brightness
- Ctrl + Right Shift: Decrease keyboard backlight brightness
- Sym + Enter: Put the keyboard into sleep mode (with keyboard backlight turned off)

# Adding key combinations

Using the Key Mapper app by sds100 you can add more advanced key combinations that an USB keyboard can't just do on it's own. I currently use the following shortcuts, but feel free to do whatever you want.

- Alt + P: Recents
- Alt + Backspace: Back
- Alt + Enter: Home
- Alt + O: Split screen
- Alt + L: Flashlight
- Alt + $: Rotate screen

You can also use the "Key pressed" block in the Automate app by llamalab to trigger more complex actions using the keyboard.

# Customizable software keyboard for missing characters

Since the Blackberry Q10 keyboard doesn't contain all possible characters I use [Keyboard Designer](https://play.google.com/store/apps/details?id=de.humbergsoftware.keyboarddesigner) to add an one-row software keyboard containing characters that I frequently use but are not on the BBQ10 keyboard.

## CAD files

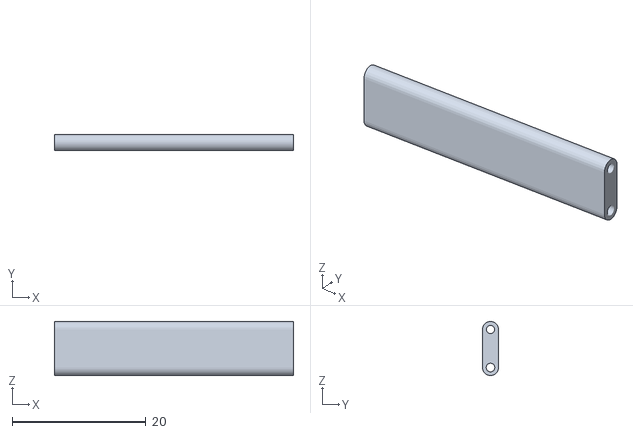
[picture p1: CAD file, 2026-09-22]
Case/WriterDeck/reference/xteinkflipcaseHINGE.stl
35.8 x 2.40 x 8.10

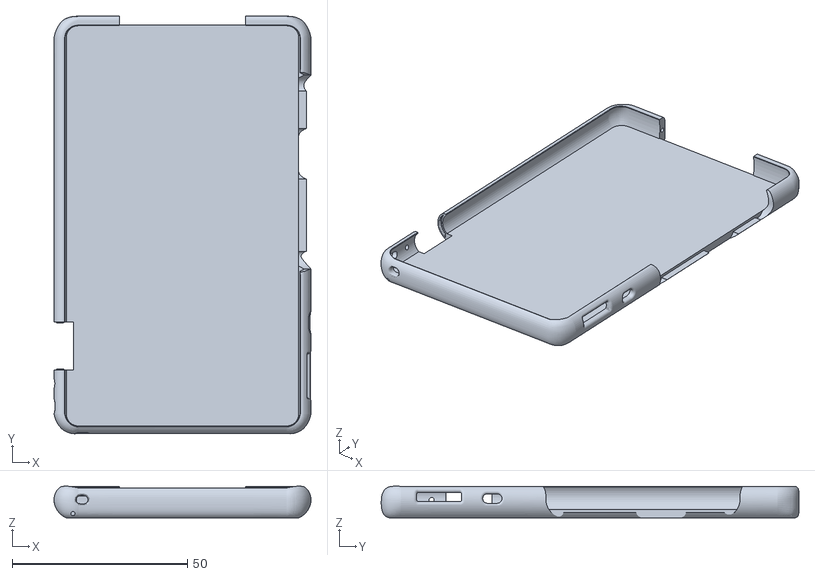
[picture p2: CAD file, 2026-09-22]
Case/WriterDeck/reference/xteinkflipcaseBOTTOM.stl
73.3 x 119.1 x 9.05

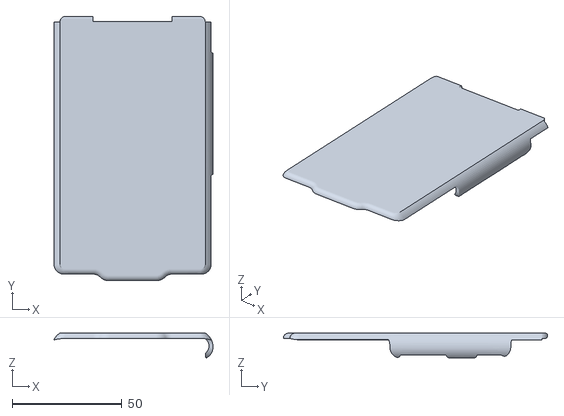
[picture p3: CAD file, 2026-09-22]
Case/WriterDeck/reference/xteinkflipcaseTOP.stl
72.5 x 120.6 x 11.3

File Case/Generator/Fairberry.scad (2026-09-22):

// Fairberry Keyboard Case Generator © 2024 by Dakkaron is licensed under Attribution-NonCommercial-ShareAlike 4.0 International.
// To view a copy of this license, visit http://creativecommons.org/licenses/by-nc-sa/4.0/
// Version 2

SCREEN_PROTECTOR_HEIGHT=0.6; // Thickness of the screen protector
EXTRUSION_WIDTH=0.48; // Extrusion width of your 3D printer

// Uncomment the type of device you use. If your device doesn't appear in this list, leave "include <presets/Custom.scad>" and edit the file at presets/Custom.scad to fit your device.
//include <presets/Custom.scad>
include <presets/XteinkX4.scad>
//include <presets/SamsungGalaxyA54.scad>
//include <presets/Fairphone4.scad>


_KEYBOARD_CATCH_DEPTH=1.5;
_ELECTRONICS_CUTAWAY_TOP_CLEARANCE=5;
_ELECTRONICS_BAY_TOPWALL_THICKNESS=0.5;
_ELECTRONICS_CUTAWAY_WIDTH=60.0;
_ELECTRONICS_CUTAWAY_BACKWALL_EXTRAPERIMETERS=5;
_ELECTRONICS_CUTAWAY_THICKNESS=PHONE_THICKNESS+SCREEN_PROTECTOR_HEIGHT+KEYBOARD_PHONE_GAP_PERIMETERS*EXTRUSION_WIDTH-_ELECTRONICS_CUTAWAY_BACKWALL_EXTRAPERIMETERS*EXTRUSION_WIDTH;
_ELECTRONICS_CUTAWAY_LENGTH=25;
_KEYBOARD_THICKNESS=3.6;
_CASE_BOTTOM_LENGTH=38;
_CASE_KEYBOARD_Y_OVERLAP=EXTRUSION_WIDTH*2;

_USB_PORT_CUTAWAY_WIDTH=10;
_USB_PORT_CUTAWAY_HEIGHT=3.5;
_USB_PORT_CUTAWAY_LENGTH=20;
_USB_PORT_ROUNDING_RADIUS=2;

//Case cannot get smaller than 70mm, due to keyboard width
CASE_WIDTH=max(PHONE_WIDTH, 70.0) + EXTRUSION_WIDTH*PERIMETERS*2;
CASE_THICKNESS=PHONE_THICKNESS + EXTRUSION_WIDTH*CASE_BOTTOM_PERIMETERS + _KEYBOARD_THICKNESS + SCREEN_PROTECTOR_HEIGHT + KEYBOARD_PHONE_GAP_PERIMETERS*EXTRUSION_WIDTH;

assert(CASE_ROUNDING_RADIUS*2<PHONE_THICKNESS+2*CASE_BOTTOM_PERIMETERS*EXTRUSION_WIDTH, "Error: CASE_ROUNDING_RADIUS needs to be smaller than PHONE_THICKNESS + 2*CASE_BOTTOM_PERIMETERS*EXTRUSION_WIDTH");

include <include/roundedcube.scad>
include <include/roundedCorner.scad>

$fn=$preview ? 20 : 100;

module keyboardDummy() {
    color("darkgrey")
    translate([0,0.11,PHONE_THICKNESS/2 + SCREEN_PROTECTOR_HEIGHT + KEYBOARD_PHONE_GAP_PERIMETERS*EXTRUSION_WIDTH])
        import("import/BBQ10KBD.stl", convexity=5);
}

module usbPortCutaway() {
    translate([-_USB_PORT_CUTAWAY_WIDTH/2, -_USB_PORT_CUTAWAY_LENGTH/2, -_USB_PORT_CUTAWAY_HEIGHT/2-USB_PORT_Y_OFFSET])
    roundedcube(size=[_USB_PORT_CUTAWAY_WIDTH, _USB_PORT_CUTAWAY_LENGTH, _USB_PORT_CUTAWAY_HEIGHT], center=false, radius=_USB_PORT_ROUNDING_RADIUS, apply_to=["y"]);
}

module speakerHole() {
    translate([-PHONE_SPEAKER_CUTAWAY_WIDTH/2+PHONE_SPEAKER_CUTAWAY_DISTANCE_FROM_CENTER, -_USB_PORT_CUTAWAY_LENGTH/2, -_USB_PORT_CUTAWAY_HEIGHT/2])
    roundedcube(size=[PHONE_SPEAKER_CUTAWAY_WIDTH, _USB_PORT_CUTAWAY_LENGTH, _USB_PORT_CUTAWAY_HEIGHT], center=false, radius=_USB_PORT_ROUNDING_RADIUS, apply_to=["y"]);
}

module phoneDummy() {
    union() {
        if (PHONE_DUMMY_FILE==""){
            color("purple")
            translate([0,-PHONE_KEYBOARD_OVERLAP,0])
            union() {
                translate([-PHONE_WIDTH/2, 0, -PHONE_THICKNESS/2])
                roundedcube(size=[PHONE_WIDTH, 50+CASE_SLEEVE_LENGTH, PHONE_THICKNESS], center=false, radius=PHONE_ROUNDING_RADIUS, apply_to=["all"]);
                usbPortCutaway();
                speakerHole();
            }
        } else {
            color("purple")
            translate([0,-PHONE_KEYBOARD_OVERLAP,0])
            scale([1.015,1.00,1.11]) //TOLLERANCE
            import(PHONE_DUMMY_FILE, convexity=5);
            if (FORCE_HOLE_CUTAWAYS) {
                usbPortCutaway();
                speakerHole();
            }
        }
        if (SCREEN_PROTECTOR_HEIGHT>0) {
            color("blue")
            translate([-PHONE_WIDTH/2+PHONE_ROUNDING_RADIUS/2, -PHONE_KEYBOARD_OVERLAP+.15, PHONE_THICKNESS/2])
            cube(size=[PHONE_WIDTH-PHONE_ROUNDING_RADIUS, PHONE_KEYBOARD_OVERLAP, SCREEN_PROTECTOR_HEIGHT], center=false);
        }
    }
}

module phoneRoundingBox() {
    translate([-CASE_WIDTH/2,_CASE_KEYBOARD_Y_OVERLAP-_CASE_BOTTOM_LENGTH,-PHONE_THICKNESS/2 - EXTRUSION_WIDTH*CASE_BOTTOM_PERIMETERS])
    hull() {
        difference() {
            intersection() {
                roundedcube(size=[CASE_WIDTH,_CASE_BOTTOM_LENGTH+100, CASE_THICKNESS + CASE_TOP_ROUNDING_OFFSET], center=false, radius=CASE_ROUNDING_RADIUS, apply_to=["all"]);
                //translate([0,0,-50])
                
                roundedcube(size=[CASE_WIDTH,_CASE_BOTTOM_LENGTH+150, CASE_THICKNESS + CASE_TOP_ROUNDING_OFFSET + 50], center=false, radius=CASE_BOTTOM_ROUNDING_RADIUS, apply_to=["z"]);
                
                roundedcube(size=[CASE_WIDTH,_CASE_BOTTOM_LENGTH+150, CASE_THICKNESS + CASE_TOP_ROUNDING_OFFSET + 50], center=false, radius=CASE_BOTTOM_ROUNDING_RADIUS, apply_to=["x"]);
            }
            color("blue")
            roundedCornerNegative([CASE_BOTTOM_ROUNDING_RADIUS,CASE_BOTTOM_ROUNDING_RADIUS+5,CASE_BOTTOM_ROUNDING_RADIUS]);
            
            translate([CASE_WIDTH,0,0])
            mirror([1,0,0])
            color("blue")
            roundedCornerNegative([CASE_BOTTOM_ROUNDING_RADIUS,CASE_BOTTOM_ROUNDING_RADIUS+5,CASE_BOTTOM_ROUNDING_RADIUS]);
        }
    }
}

module case() {
    translate([-CASE_WIDTH/2, _CASE_KEYBOARD_Y_OVERLAP-_CASE_BOTTOM_LENGTH-1, -PHONE_THICKNESS/2 - EXTRUSION_WIDTH*CASE_BOTTOM_PERIMETERS])
    cube(size=[CASE_WIDTH, _CASE_BOTTOM_LENGTH, CASE_THICKNESS], center=false);
}

module caseSleeve() {
    difference() {
        translate([-CASE_WIDTH/2, -1, -PHONE_THICKNESS/2-0.05 - EXTRUSION_WIDTH*CASE_BOTTOM_PERIMETERS])
        roundedcube(size=[CASE_WIDTH, CASE_SLEEVE_LENGTH+1, PHONE_THICKNESS+EXTRUSION_WIDTH*(CASE_BOTTOM_PERIMETERS+CASE_SLEEVE_TOP_PERIMETERS)-0.05], center=false, radius=CASE_SLEEVE_ROUNDING_RADIUS, apply_to=["y"]);
        
        translate([-PHONE_WIDTH/2+PHONE_ROUNDING_RADIUS/2, -1.5, -0.05])
        cube(size=[PHONE_WIDTH-PHONE_ROUNDING_RADIUS, CASE_SLEEVE_LENGTH+3, PHONE_THICKNESS+EXTRUSION_WIDTH*CASE_BOTTOM_PERIMETERS*2-0.05], center=false);
    }
}

module caseSleeveLink() {
    scaleFactor = 2*CASE_THICKNESS/(PHONE_THICKNESS+EXTRUSION_WIDTH*CASE_BOTTOM_PERIMETERS*2-0.05);
    translate([0, CASE_SLEEVE_LINK_LENGTH-1.5, 0])
    intersection() {
        /*{
            translate([-CASE_WIDTH/2, -51, -PHONE_THICKNESS/2-0.05 - EXTRUSION_WIDTH*CASE_BOTTOM_PERIMETERS])
            roundedcube(size=[CASE_WIDTH, CASE_SLEEVE_LENGTH+100, 100+PHONE_THICKNESS+EXTRUSION_WIDTH*CASE_BOTTOM_PERIMETERS*2-0.05], center=false, radius=CASE_SLEEVE_ROUNDING_RADIUS, apply_to=["y"]);
        }*/
        {
            rotate([-90,0,180])
            linear_extrude(height=CASE_SLEEVE_LINK_LENGTH,scale=[1,scaleFactor],slices=100) {
                projection()
                rotate([90,0,0])
                caseSleeve();
            }
        }
        case();
    }
}

module electronicsCutaway() {
    
    union() {
        color("pink")
        translate([-_ELECTRONICS_CUTAWAY_WIDTH/2, -PHONE_KEYBOARD_OVERLAP-_ELECTRONICS_BAY_TOPWALL_THICKNESS-_ELECTRONICS_CUTAWAY_LENGTH, -PHONE_THICKNESS/2+0.01+_ELECTRONICS_CUTAWAY_BACKWALL_EXTRAPERIMETERS*EXTRUSION_WIDTH])
        cube(size=[_ELECTRONICS_CUTAWAY_WIDTH, _ELECTRONICS_CUTAWAY_LENGTH, _ELECTRONICS_CUTAWAY_THICKNESS], center=false);
        
        /*color("red")
        translate([-_ELECTRONICS_CUTAWAY_WIDTH/2+0.005,
            -_ELECTRONICS_CUTAWAY_TOP_CLEARANCE-_ELECTRONICS_CUTAWAY_LENGTH,
            PHONE_THICKNESS*.5+EXTRUSION_WIDTH])
        cube(size=[_ELECTRONICS_CUTAWAY_WIDTH-0.01, _ELECTRONICS_CUTAWAY_LENGTH, (KEYBOARD_PHONE_GAP_PERIMETERS*2-1) * EXTRUSION_WIDTH], center=false);*/
    }
}

module usbAnvilCutaway() {
    color("teal")
    translate([0,-PHONE_KEYBOARD_OVERLAP-7,-USB_PORT_Y_OFFSET-2])
    cube([35,13,2], center=true);
}

module usbAnvil() {
    translate([0,-PHONE_KEYBOARD_OVERLAP,-USB_PORT_Y_OFFSET])
    import("import/USB_Anvil.stl");
}

module screwM3Countersunk(length) {
    union() {
        cylinder(length,d1=3,d2=3,center=true);
        translate([0,0,-10])
        cylinder(2,d1=6.5,d2=3,center=true);
        translate([0,0,-16])
        cylinder(10,d1=6.5,d2=6.5,center=true);
    }
}

module screwM2(length) {
    union() {
        translate([0, 0, -length])
        cylinder(length,d1=2,d2=2,center=false);
        translate([0,0,-length-10])
        cylinder(10,d1=3.5,d2=3.5,center=false);
    }
}

module usbScrewHoles() {
    union() {
        translate([-10,-PHONE_KEYBOARD_OVERLAP-4.25,5])
        screwM3Countersunk(20);
        translate([10,-PHONE_KEYBOARD_OVERLAP-4.25,5])
        screwM3Countersunk(20);
    }
}
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

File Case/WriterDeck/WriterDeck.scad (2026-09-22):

// Writer Deck combined case -- Fairberry keyboard + Xteink X4, one clamshell.
// See Case/WriterDeck/README.md for the full reasoning and what's still
// unverified here.
//
// STRATEGY: don't reinvent the hinge. The user-provided reference model
// (Case/WriterDeck/reference/, an "XteinkX4FullCoverageFlipCase") has a
// real, evidently-tested 3-piece interlocking hinge:
//   - BOTTOM: the X4 cradle (27590 triangles -- has the device-specific
//     port/button cutouts). Reused here completely unmodified.
//   - HINGE: a separate comb+pin bar, X 15.06-50.86mm, that meshes with
//     knuckle teeth on both BOTTOM and the (replaced) TOP. Reused
//     unmodified.
//   - TOP: in the reference, a plain flip-lid (11760 triangles, much
//     simpler than BOTTOM -- no device-specific cutouts). This is what
//     gets replaced with the keyboard half below. Only TOP's two corner
//     hinge-knuckle loops are reused (extracted via intersection(), see
//     hingeKnuckleLoops() below) -- the flat lid body itself is discarded
//     and replaced with the keyboard tray.
//
// Coordinate system matches the reference files' own: this draws the
// CLOSED position (keyboard half stacked on top of the X4 cradle, same
// footprint), matching how BOTTOM/TOP were modeled relative to each other
// in the original. The two halves are meant to be printed in this
// relative arrangement, then the hinge pin threaded through after
// printing -- same assembly process the reference case itself would use.
//
// UNVERIFIED (see README): keyboard tray cavity depth/height for the
// FAIRBERRY_ESP32S3_SMART board + battery + trackball stack (no PCB
// exists yet to measure against -- see Documentation/Hardware_Standalone_
// Smart_Keyboard.md's own "no enclosure yet" note, which still applies),
// trackball/mic/speaker cutout positions, wall thickness/hinge alignment
// tolerance (not print-tested).

$fn = $preview ? 24 : 60;

// ---- Reused reference geometry (unmodified) ----

module x4Cradle() {
  import("reference/xteinkflipcaseBOTTOM.stl", convexity=6);
}

module hingePin() {
  import("reference/xteinkflipcaseHINGE.stl", convexity=6);
}

// Extracts just the two corner hinge-knuckle loops from the reference
// TOP piece (bounding boxes measured directly off the mesh -- see the
// analysis in this repo's session history, not eyeballed). The rest of
// TOP (the flat lid body) is intentionally discarded.
module hingeKnuckleLoops() {
  intersection() {
    import("reference/xteinkflipcaseTOP.stl", convexity=6);
    union() {
      translate([-4, 104, 5.5]) cube([14, 14, 4]);   // left loop
      translate([59, 104, 5.5]) cube([12, 14, 4]);   // right loop
    }
  }
}

// ---- New keyboard half ----
// Same X-Y footprint as the X4 cradle (0-70 x 0-~117) so the extracted
// knuckle loops land in the right place and the two halves stack/close
// flush, matching the reference's own BOTTOM/TOP relationship.

TRAY_WIDTH = 70;
TRAY_LENGTH = 117;
TRAY_WALL = 2;                 // UNVERIFIED -- not tuned against any specific printer/tolerance yet
TRAY_FLOOR_Z = 6.0;            // Sits where the reference's TOP started (see file header) -- keeps knuckle loops aligned without needing to re-derive their Z position
KEYBOARD_CAVITY_HEIGHT = 8;    // UNVERIFIED -- rough guess for keyboard module (5.2mm, per Case/Generator/import/BBQ10KBD.stl) + mainboard PCB + clearance. No PCB exists yet for FAIRBERRY_ESP32S3_SMART to measure against; see Documentation/Hardware_Standalone_Smart_Keyboard.md

// Real, measured keyboard module dimensions (Case/Generator/import/BBQ10KBD.stl: 66.558 x 36.044 x 5.225mm), not guessed.
KEYBOARD_MODULE_WIDTH = 66.6;
KEYBOARD_MODULE_LENGTH = 36.1;

// Placed with its far (non-hinge) edge near Y=8 and extending toward the
// hinge, leaving room between the keyboard and the hinge edge for the
// trackball -- BlackBerry-style, trackball between the keys and the
// screen so it's naturally reachable while looking at the display when
// the deck is open. Tune KEYBOARD_Y_OFFSET to adjust.
KEYBOARD_Y_OFFSET = 8;

module keyboardCutout() {
  translate([(TRAY_WIDTH - KEYBOARD_MODULE_WIDTH)/2, KEYBOARD_Y_OFFSET, -1])
    cube([KEYBOARD_MODULE_WIDTH, KEYBOARD_MODULE_LENGTH, KEYBOARD_CAVITY_HEIGHT + 2]);
}

// Trackball module footprint (ICSH044A / SparkFun-clone, ~28x22x8mm per
// Documentation/Hardware_ESP32_Trackball_Mainboard.md's BOM) -- placed
// near the hinge edge, centered, per the BlackBerry-style reasoning
// above. Position is a first guess, not fitted to anything.
TRACKBALL_WIDTH = 28;
TRACKBALL_LENGTH = 22;
TRACKBALL_Y = TRAY_LENGTH - 30; // 30mm in from the hinge edge

module trackballCutout() {
  translate([(TRAY_WIDTH - TRACKBALL_WIDTH)/2, TRACKBALL_Y, -1])
    cube([TRACKBALL_WIDTH, TRACKBALL_LENGTH, KEYBOARD_CAVITY_HEIGHT + 2]);
}

module keyboardTrayShell() {
  // Open-top tray: walls + floor only, no lid (electronics drop in from
  // above, same idea as the existing Fairberry.scad case). The inner cut
  // deliberately overshoots the top face so it's a clean through-cut
  // rather than stopping short and leaving an accidental thin ceiling.
  translate([0, 0, TRAY_FLOOR_Z])
  difference() {
    cube([TRAY_WIDTH, TRAY_LENGTH, KEYBOARD_CAVITY_HEIGHT + TRAY_WALL]);
    translate([TRAY_WALL, TRAY_WALL, TRAY_WALL])
      cube([TRAY_WIDTH - 2*TRAY_WALL, TRAY_LENGTH - 2*TRAY_WALL, KEYBOARD_CAVITY_HEIGHT + 10]);
  }
}

module keyboardHalf() {
  union() {
    difference() {
      keyboardTrayShell();
      translate([0, 0, TRAY_FLOOR_Z]) keyboardCutout();
      translate([0, 0, TRAY_FLOOR_Z]) trackballCutout();
    }
    hingeKnuckleLoops();
  }
}

// ---- Assembly (closed position) ----

color("SteelBlue") x4Cradle();
color("DarkGray") hingePin();
color("Orange") keyboardHalf();

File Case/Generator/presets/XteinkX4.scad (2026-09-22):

// Xteink X4 preset for the Fairberry case generator.
//
// STILL PARTIALLY UNVERIFIED, but better grounded than a plain spec-sheet
// guess: PHONE_WIDTH/PHONE_THICKNESS below come from a community-made,
// to-scale Xteink X4 dummy model (measured off a physical unit, not just
// the rounded marketing spec of 114 x 69 x 5.9mm):
//   "Xteink X4 device model" by Zorian22, CC BY-NC-SA
//   https://www.thingiverse.com/thing:7287950
//   (companion case: https://www.thingiverse.com/thing:7287943 ;
//    parametric Onshape source: see the Thingiverse page for the link)
// That model measures 114.2 x 69.2 x 6.2mm at its widest/thickest points.
//
// This preset still doesn't use that model directly (see PHONE_DUMMY_FILE
// below) -- it only borrows its measured width/thickness for the
// parametric (no-dummy-file) case body. PHONE_KEYBOARD_OVERLAP and
// USB_PORT_Y_OFFSET are still unverified guesses, and side page-turn
// button cutouts still aren't modeled at all.
//
// For a real fit instead of an approximation:
// 1. Download the .3mf from the Thingiverse link above yourself (Claude
//    can't do this step -- Thingiverse's terms explicitly block automated
//    fetching, so this needs a normal browser download).
// 2. Convert it to .stl if needed (OpenSCAD's import() wants stl/off/amf
//    for this repo's existing convention; recent OpenSCAD can import .3mf
//    directly, but converting keeps this consistent with the phone
//    presets) and save it as Case/Generator/import/XteinkX4_Dummy.stl.
// 3. Set PHONE_DUMMY_FILE below to "import/XteinkX4_Dummy.stl" instead of
//    "". This switches Fairberry.scad to cut the case around the actual
//    modeled device shape instead of a plain rounded box, which should
//    also surface the button geometry that model includes.
// Either way: print a bottom-only test fit before committing to a full
// case -- these numbers have not been validated against my own unit yet.

//Phone dimensions in mm
PHONE_WIDTH=69.2;
PHONE_THICKNESS=6.2;
PHONE_KEYBOARD_OVERLAP=8; // Unverified guess, adjust to your device
USB_PORT_Y_OFFSET=0; // Assumed centered, verify against your unit

GENERATE_TOP_CASE=false; // If set to false, will generate the keyboard case. If set to true, will instead create the top case

// Leave empty ("") to generate the phone shape using this script.
// See step 1-3 above for switching this to the real dummy model.
PHONE_DUMMY_FILE="";

// The X4 has no speaker. Fairberry.scad always cuts this slot when
// PHONE_DUMMY_FILE=="" (the cutout is a fixed-radius hull, so setting the
// width to 0 does NOT remove it, it just leaves a ~4mm slot) — it will show
// up as a small non-functional vent near the USB cutout. Harmless, but if
// you want a fully solid case bottom there, remove the speakerHole() call
// from phoneDummy() in Fairberry.scad.
PHONE_SPEAKER_CUTAWAY_WIDTH=4;
PHONE_SPEAKER_CUTAWAY_DISTANCE_FROM_CENTER=18;

// Corner radius of the device. Only relevant since PHONE_DUMMY_FILE==""
PHONE_ROUNDING_RADIUS=6;

PERIMETERS=4; // How many perimeters should the top part of the case be thick?

// How many perimeters should the case be thick below the device?
CASE_BOTTOM_PERIMETERS=3;

CASE_SLEEVE_TOP_PERIMETERS=2;
CASE_SLEEVE_LENGTH=28.5; // Length of the case extension towards the top of the device
CASE_SLEEVE_LINK_LENGTH=5;
CASE_SLEEVE_ROUNDING_RADIUS=4; // Corner radius of the sleeve part of the case.
CASE_ROUNDING_RADIUS=4; // Corner radius of the case. Must stay well below PHONE_THICKNESS since the X4 is thin.
CASE_BOTTOM_ROUNDING_RADIUS=10;
CASE_TOP_ROUNDING_OFFSET=1; // Increasing this number makes the top less rounded

KEYBOARD_PHONE_GAP_PERIMETERS=2; // Thickness of the separator between keyboard and device screen

KEYBOARD_CATCH_DEPTH=1.5;

FORCE_HOLE_CUTAWAYS=true; // Will cut holes for USB even if a dummy file is selected. Use this if the holes aren't included in the dummy file.

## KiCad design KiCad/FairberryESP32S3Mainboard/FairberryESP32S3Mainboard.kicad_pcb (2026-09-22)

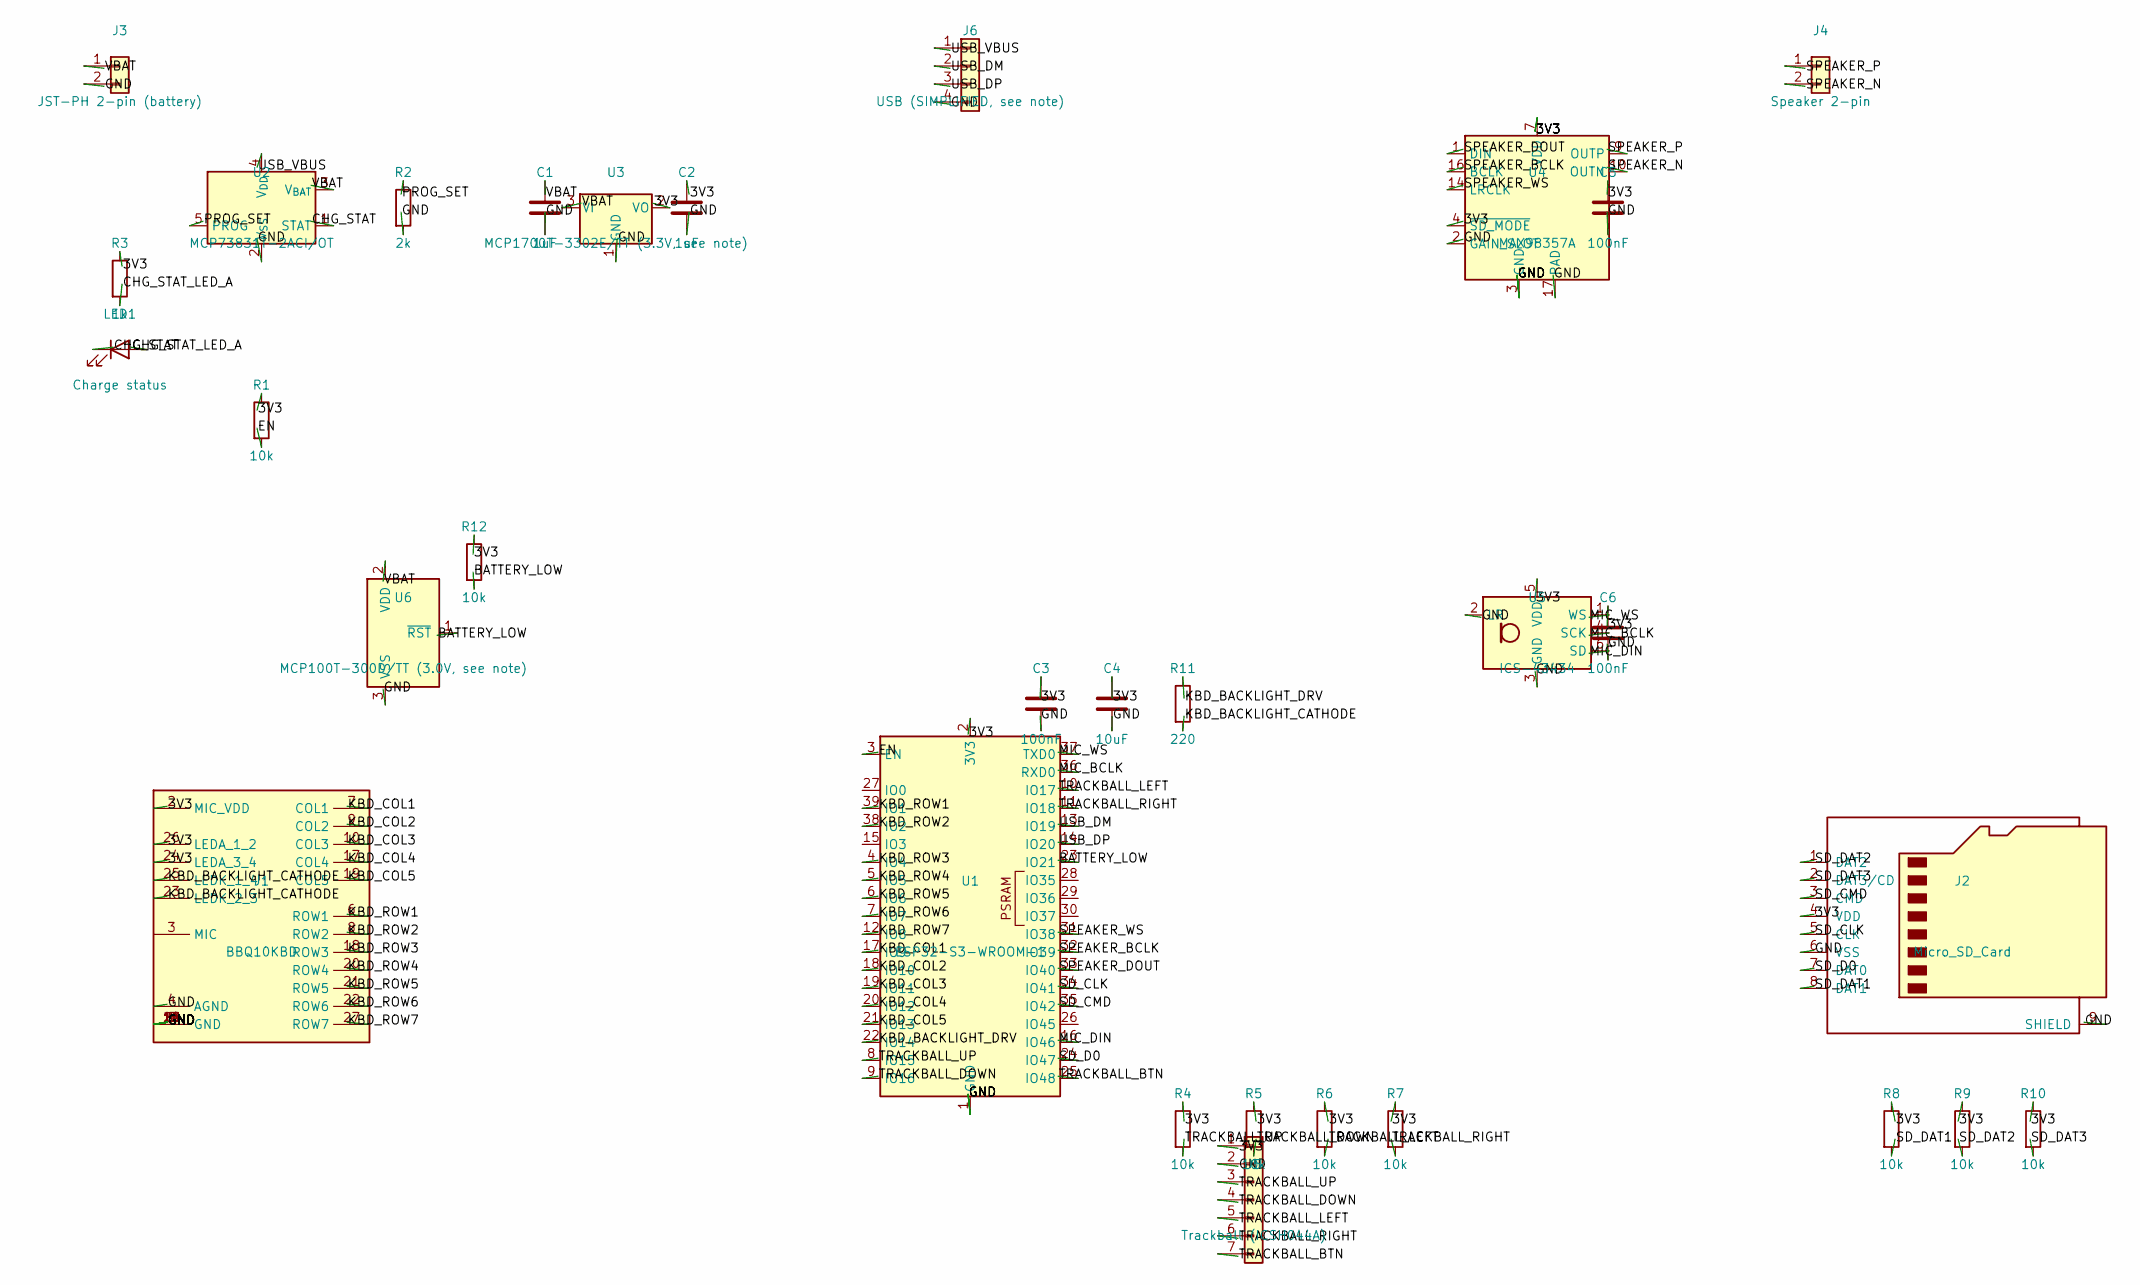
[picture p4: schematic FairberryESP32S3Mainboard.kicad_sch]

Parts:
C1, C2: 1uF; C_0603_1608Metric
C3, C5, C6: 100nF; C_0603_1608Metric
C4: 10uF; C_0603_1608Metric
J1: BBQ10KBD; BM14B(0.8)-24DS-0.4V(53)
J2: Micro_SD_Card; microSD_HC_Wuerth_693072010801
J3: JST-PH 2-pin (battery); PinHeader_1x02_P2.54mm_Vertical
J4: Speaker 2-pin; PinHeader_1x02_P2.54mm_Vertical
J5: Trackball (ICSH044A); PinHeader_1x07_P2.54mm_Vertical
J6: USB (SIMPLIFIED, see note); PinHeader_1x04_P2.54mm_Vertical
LED1: Charge status; LED_0603_1608Metric
R1, R4, R5, R6, R7, R8, R9, R10, R12: 10k; R_0603_1608Metric
R2: 2k; R_0603_1608Metric
R3: 1k; R_0603_1608Metric
R11: 220; R_0603_1608Metric
U1: ESP32-S3-WROOM-1
U2: MCP73831T-2ACI/OT; SOT-23-5
U3: MCP1700T-3302E/TT (3.3V, see note); SOT-23
U4: MAX98357A; TQFN-16-1EP_3x3mm_P0.5mm_EP1.23x1.23mm
U5: ICS-43434; InvenSense_ICS-43434-6_3.5x2.65mm
U6: MCP100T-300D/TT (3.0V, see note); SOT-23-3

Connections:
3V3: C2.1, C3.1, C4.1, C5.1, C6.1, J1.2 (MIC_VDD), J1.24 (LEDA_3_4), J1.26 (LEDA_1_2), J2.4 (VDD), J5.1, R1.1, R3.1, R4.1, R5.1, R6.1, R7.1, R8.1, R9.1, R10.1, R12.1, U1.2 (3V3), U3.2 (VO), U4.4 (~SD_MODE), U4.7 (VDD), U4.8 (VDD), U5.5 (VDD)
BATTERY_LOW: R12.2, U1.23 (IO21), U6.1 (~RST)
CHG_STAT: LED1.1 (K), U2.1 (STAT)
CHG_STAT_LED_A: LED1.2 (A), R3.2
EN: R1.2, U1.3 (EN)
GND: C1.2, C2.2, C3.2, C4.2, C5.2, C6.2, J1.1 (GND), J1.4 (AGND), J1.5 (GND), J1.11 (GND), J1.12 (GND), J1.13 (GND), J1.14 (GND), J1.15 (GND), J1.16 (GND), J1.28 (GND), J2.6 (VSS), J2.9 (SHIELD), J3.2, J5.2, J6.4, R2.2, U1.1 (GND), U1.40 (GND), U1.41 (GND), U2.2 (V_{SS}), U3.1 (GND), U4.2 (GAIN_SLOT), U4.3 (GND), U4.11 (GND), U4.15 (GND), U4.17 (PAD), U5.2 (LR), U5.3 (GND), U6.3 (VSS)
KBD_BACKLIGHT_CATHODE: J1.23 (LEDK_2_3), J1.25 (LEDK_1_4), R11.2
KBD_BACKLIGHT_DRV: R11.1, U1.22 (IO14)
KBD_COL1: J1.7 (COL1), U1.17 (IO9)
KBD_COL2: J1.9 (COL2), U1.18 (IO10)
KBD_COL3: J1.10 (COL3), U1.19 (IO11)
KBD_COL4: J1.17 (COL4), U1.20 (IO12)
KBD_COL5: J1.19 (COL5), U1.21 (IO13)
KBD_ROW1: J1.6 (ROW1), U1.39 (IO1)
KBD_ROW2: J1.8 (ROW2), U1.38 (IO2)
KBD_ROW3: J1.18 (ROW3), U1.4 (IO4)
KBD_ROW4: J1.20 (ROW4), U1.5 (IO5)
KBD_ROW5: J1.21 (ROW5), U1.6 (IO6)
KBD_ROW6: J1.22 (ROW6), U1.7 (IO7)
KBD_ROW7: J1.27 (ROW7), U1.12 (IO8)
MIC_BCLK: U1.36 (RXD0), U5.4 (SCK)
MIC_DIN: U1.16 (IO46), U5.6 (SD)
MIC_WS: U1.37 (TXD0), U5.1 (WS)
PROG_SET: R2.1, U2.5 (PROG)
SD_CLK: J2.5 (CLK), U1.34 (IO41)
SD_CMD: J2.3 (CMD), U1.35 (IO42)
SD_D0: J2.7 (DAT0), U1.24 (IO47)
SD_DAT1: J2.8 (DAT1), R8.2
SD_DAT2: J2.1 (DAT2), R9.2
SD_DAT3: J2.2 (DAT3/CD), R10.2
SPEAKER_BCLK: U1.32 (IO39), U4.16 (BCLK)
SPEAKER_DOUT: U1.33 (IO40), U4.1 (DIN)
SPEAKER_N: J4.2, U4.10 (OUTN)
SPEAKER_P: J4.1, U4.9 (OUTP)
SPEAKER_WS: U1.31 (IO38), U4.14 (LRCLK)
TRACKBALL_BTN: J5.7, U1.25 (IO48)
TRACKBALL_DOWN: J5.4, R5.2, U1.9 (IO16)
TRACKBALL_LEFT: J5.5, R6.2, U1.10 (IO17)
TRACKBALL_RIGHT: J5.6, R7.2, U1.11 (IO18)
TRACKBALL_UP: J5.3, R4.2, U1.8 (IO15)
USB_DM: J6.2, U1.13 (IO19)
USB_DP: J6.3, U1.14 (IO20)
USB_VBUS: J6.1, U2.4 (V_{DD})
VBAT: C1.1, J3.1, U2.3 (V_{BAT}), U3.3 (VI), U6.2 (VDD)

Board: 2 copper layers, 31 parts (0 on the bottom side), 44 nets, no tracks yet.

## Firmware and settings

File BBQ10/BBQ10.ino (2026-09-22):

// Fairberry Keyboard Firmware © 2024 by Dakkaron is licensed under Attribution-NonCommercial-ShareAlike 4.0 International.
// To view a copy of this license, visit http://creativecommons.org/licenses/by-nc-sa/4.0/
// Version 3

#define FAIRBERRY_V0_3_0 3
#define FAIRBERRY_V0_2_0 2
#define FAIRBERRY_V0_1_1 1
#define ARDUINO 10
#define BEETLE 1101
#define ESP32 1102
#define FAIRBERRY_ESP32S3_SMART 1103


#define CHIP_ATMEGA32U4 1
#define CHIP_ESP32 2

#include "configuration.h"
#include "constants.h"
#include "keymaps.h"
#include "boards.h"
#include "trackball.h"
#include "storage.h"
#include "audio.h"
#include "wifi_conn.h"
#include "whisper_sync.h"
#include "tts.h"
#include "keystroke_util.h"
#include "voice_typing.h"
#include "web_server.h"


bool keys[colCount][rowCount];
bool lastValue[colCount][rowCount];
bool changedValue[colCount][rowCount];
byte debounceMs[colCount][rowCount];
unsigned long lastDebounceMs;


int keyboardLightSteps = 20;
int keyboardLight1 = DEFAULT_KEYBOARD_BRIGHTNESS;
int keyboardLight2 = DEFAULT_KEYBOARD_BRIGHTNESS;
volatile unsigned long idleTimeout = millis() + IDLE_TIMEOUT;
volatile unsigned long blinkTimeout = millis() + BLINK_TIMEOUT;
volatile bool isClockedDown = false;
bool blinkState = true;
bool idleWakeup = false;
bool firstSleep = true;
bool connectionNeedsReinit = false;

#define USB_ADDRESS_EXISTS (_BV(ADDEN)==0x80 && UDINT > 0)
bool usbGotDisconnected = false;

bool anyKeyReleased = false;

byte stickySym = STICKY_STATUS_OPEN;
byte stickyLsh = STICKY_STATUS_OPEN;
byte stickyRsh = STICKY_STATUS_OPEN;
byte stickyCtrl = STICKY_STATUS_OPEN;
byte stickyAlt = STICKY_STATUS_OPEN;

bool keyboardInit = false;
bool cursorMode = false;

void(* resetFunc) (void) = 0;

void setup() {
    #ifdef LED0_PIN
      pinMode(LED0_PIN, OUTPUT);
    #endif
    #ifdef LED1_PIN
      pinMode(LED1_PIN, OUTPUT);
    #endif
    #if BOARD_TYPE == ESP32 || BOARD_TYPE == FAIRBERRY_ESP32S3_SMART
      KEYBOARD_BEGIN(KeyboardLayout_en_US);
      keyboardInit = true;
    #endif
    #if BOARD_TYPE == ESP32
      // Not run for FAIRBERRY_ESP32S3_SMART: esp_pm_config_esp32_t is a
      // classic-ESP32-specific struct name that wouldn't compile as-is on
      // S3 (IDF names this per-chip, e.g. esp_pm_config_esp32s3_t on
      // older cores, or a generic esp_pm_config_t on newer ones -- rather
      // than guess which applies to your toolchain, this is just skipped
      // for now on the S3 board type). More importantly, disabling WiFi
      // here would break the whole point of that board type, which needs
      // WiFi for the Whisper sync.
      esp_bt_sleep_enable();

      esp_pm_config_esp32_t pm_config;
      pm_config.max_freq_mhz = 80;
      pm_config.min_freq_mhz = 80;
      pm_config.light_sleep_enable = true;
      esp_pm_configure(&pm_config);

      esp_wifi_set_mode(WIFI_MODE_NULL);
    #endif
    for(int i=0; i<rowCount; i++) {
        #ifdef SERIAL_DEBUG_LOG
          Serial.print(rows[i]); Serial.println(" as input");
        #endif
        pinMode(rows[i], INPUT);
    }
 
    for (int i=0; i<colCount; i++) {
        #ifdef SERIAL_DEBUG_LOG
          Serial.print(cols[i]); Serial.println(" as input-pullup");
        #endif
        #ifdef FASTCOLS
          FASTCOLS_PINCONFIG = FASTCOLS_PINCONFIG & !(1 << cols[i]);
          FASTCOLS_PORT = FASTCOLS_PORT & !(1 << cols[i]);
        #else
          pinMode(cols[i], INPUT);
        #endif
    }

    // set pins for the keyboard backlight
    #ifdef KEYBOARD_LIGHT_PIN_1
      pinMode(KEYBOARD_LIGHT_PIN_1, OUTPUT);
    #endif
    #ifdef KEYBOARD_LIGHT_PIN_2
      pinMode(KEYBOARD_LIGHT_PIN_2, OUTPUT);
    #endif

    setKeyboardBacklight(keyboardLight1, keyboardLight2, true);
    lastDebounceMs = millis();

    // USBDevice/USBCON/USBE are AVR (ATmega32u4) core internals and don't
    // exist on ESP32 -- this was previously unconditional, which meant
    // BOARD_TYPE ESP32 could never actually compile. BLE init already
    // happened above via KEYBOARD_BEGIN(); there's no separate USB
    // attach step needed on that path.
    #if BOARD_TYPE != ESP32 && BOARD_TYPE != FAIRBERRY_ESP32S3_SMART
      while (USBDevice.isSuspended()) {}
      USBCON |= (1 << USBE);
      USBDevice.attach();
    #endif

    #if defined(TRACKBALL_ENABLED) && (BOARD_TYPE == ESP32 || BOARD_TYPE == FAIRBERRY_ESP32S3_SMART)
      trackballInit();
    #endif

    #if defined(AUDIO_ENABLED) && BOARD_TYPE == FAIRBERRY_ESP32S3_SMART
      storageInit();
      audioInit();
    #endif
    #if defined(WIFI_TRANSCRIPTION_ENABLED) && BOARD_TYPE == FAIRBERRY_ESP32S3_SMART
      whisperInit();
    #endif
}

void updateStickyKeyStates() {
  if (keyPressed(K_SYM) && !keyActive(K_MIC)) { // SYM(0,2) (inactive while CTRL(0,6) is held, because of brightness down)
    byte tmp = stickySym;
    resetStickyKeys();
    stickySym = tmp + 1;
  }
  if (keyPressed(K_LSH)) { // LSH(1,6)
    byte tmp = stickyLsh;
    resetStickyKeys();
    stickyLsh = tmp + 1;
  }
  if (keyPressed(K_RSH) && !keyActive(K_MIC)) { // RSH(2,3) (inactive while CTRL(0,6) is held, because of brightness down)
    byte tmp = stickyRsh;
    resetStickyKeys();
    stickyRsh = tmp + 1;
  }
  if (stickySym==STICKY_STATUS_OPEN && keyPressed(K_MIC)) { // CTRL(0,6)
    byte tmp = stickyCtrl;
    resetStickyKeys();
    stickyCtrl = tmp + 1;
  }
  if (stickySym==STICKY_STATUS_OPEN && keyPressed(K_ALT)) { // ALT(0,4)
    byte tmp = stickyAlt;
    resetStickyKeys();
    stickyAlt = tmp + 1;
  }
}

void rolloverStickyKeyStates() {
  #ifndef STICKY_SYM
    if (stickySym == STICKY_STATUS_STICKY) {
      stickySym++;
    }
  #endif
  #ifndef STICKY_LSH
    if (stickyLsh == STICKY_STATUS_STICKY) {
      stickyLsh++;
    }
  #endif
  #ifndef STICKY_RSH
    if (stickyRsh == STICKY_STATUS_STICKY) {
      stickyRsh++;
    }
  #endif
  #ifndef STICKY_CTRL
    if (stickyCtrl == STICKY_STATUS_STICKY) {
      stickyCtrl++;
    }
  #endif
  #ifndef STICKY_ALT
    if (stickyAlt == STICKY_STATUS_STICKY) {
      stickyAlt++;
    }
  #endif

  #ifndef DOUBLETAP_LOCK_SYM
    if (stickySym == STICKY_STATUS_LOCKED) {
      stickySym++;
    }
  #endif
  #ifndef DOUBLETAP_LOCK_LSH
    if (stickyLsh == STICKY_STATUS_LOCKED) {
      stickyLsh++;
    }
  #endif
  #ifndef DOUBLETAP_LOCK_RSH
    if (stickyRsh == STICKY_STATUS_LOCKED) {
      stickyRsh++;
    }
  #endif
  #ifndef DOUBLETAP_LOCK_CTRL
    if (stickyCtrl == STICKY_STATUS_LOCKED) {
      stickyCtrl++;
    }
  #endif
  #ifndef DOUBLETAP_LOCK_ALT
    if (stickyAlt == STICKY_STATUS_LOCKED) {
      stickyAlt++;
    }
  #endif

  if (stickySym > STICKY_STATUS_LOCKED) {
    stickySym = STICKY_STATUS_OPEN;
  }
  if (stickyLsh > STICKY_STATUS_LOCKED) {
    stickyLsh = STICKY_STATUS_OPEN;
  }
  if (stickyRsh > STICKY_STATUS_LOCKED) {
    stickyRsh = STICKY_STATUS_OPEN;
  }
  if (stickyCtrl > STICKY_STATUS_LOCKED) {
    stickyCtrl = STICKY_STATUS_OPEN;
  }
  if (stickyAlt > STICKY_STATUS_LOCKED) {
    stickyAlt = STICKY_STATUS_OPEN;
  }
}

void wakeEverythingUp() {
  changeKeyboardBacklight(0, 0, true);
  idleTimeout = millis() + IDLE_TIMEOUT;
  #ifdef POWERSAVE_ARDUINO_CLOCKDOWN
    if (isClockedDown) {
      CLKPR = 0b10000000;
      CLKPR = ARDUINO_CLOCKDOWN_RESET_VALUE;
      CLKPR = ARDUINO_CLOCKDOWN_RESET_VALUE;
      CLKPR = ARDUINO_CLOCKDOWN_RESET_VALUE;
      isClockedDown = false;
    }
  #endif
  #ifdef POWERSAVE_ARDUINO_POWERDOWN
    if (connectionNeedsReinit) {
      connectionNeedsReinit = false;
      while (USBDevice.isSuspended()) {}
      USBCON |= (1 << USBE);
      USBCON &= ~(1 << FRZCLK);
      USBDevice.attach();
      keyboardInit = false;
      delay(50);
      KEYBOARD_BEGIN(KeyboardLayout_en_US);
      delay(300);
    }
  #endif
  #ifdef POWERSAVE_ESP32_LIGHT_SLEEP
    if (connectionNeedsReinit) {
      pinMode(RESET_PIN, OUTPUT);
      digitalWrite(RESET_PIN, LOW);
      
      /*connectionNeedsReinit = false;
      btStart();
      KEYBOARD_BEGIN(KeyboardLayout_en_US);*/
    }
  #endif
}

boolean anyKeyPressed = false;
/**
 * Returns whether any key was changed (true == at least one key changed state)
 */
boolean readMatrix(byte debouceMsSinceLast) {
  int delayTime = 0;
  anyKeyReleased = false;
  boolean anyKeyChanged = false;
  boolean anyKeyPressed = true;
  #ifdef FASTCHECK
    #ifdef FASTCOLCHECK_D
      DDRD |= FASTCOLCHECK_D;
      PORTD &= ~FASTCOLCHECK_D;
    #endif
    #ifdef FASTROWCHECK_B
      DDRB &= ~FASTROWCHECK_B;
      PORTB |= FASTROWCHECK_B;
    #endif
    #ifdef FASTROWCHECK_C
      DDRC &= ~FASTROWCHECK_C;
      PORTC |= FASTROWCHECK_C;
    #endif
    #ifdef FASTROWCHECK_D
      DDRD &= ~FASTROWCHECK_D;
      PORTD |= FASTROWCHECK_D;
    #endif
    #ifdef FASTROWCHECK_E
      DDRE &= ~FASTROWCHECK_E;
      PORTE |= FASTROWCHECK_E;
    #endif
    #ifdef FASTROWCHECK_F
      DDRF &= ~FASTROWCHECK_F;
      PORTF |= FASTROWCHECK_F;
    #endif
    delayMicroseconds(10);
    anyKeyPressed = false;
    #ifdef FASTROWCHECK_B
      anyKeyPressed |= ((~PINB) & FASTROWCHECK_B);
      PORTB &= ~FASTROWCHECK_B;
    #endif
    #ifdef FASTROWCHECK_C
      anyKeyPressed |= ((~PINC) & FASTROWCHECK_C);
      PORTC &= ~FASTROWCHECK_C;
    #endif
    #ifdef FASTROWCHECK_D
      anyKeyPressed |= ((~PIND) & FASTROWCHECK_D);
      PORTD &= ~FASTROWCHECK_D;
    #endif
    #ifdef FASTROWCHECK_E
      anyKeyPressed |= ((~PINE) & FASTROWCHECK_E);
      PORTE &= ~FASTROWCHECK_E;
    #endif
    #ifdef FASTROWCHECK_F
      anyKeyPressed |= ((~PINF) & FASTROWCHECK_F);
      PORTF &= ~FASTROWCHECK_F;
    #endif
    #ifdef FASTCOLCHECK_D
      DDRD &= ~FASTCOLCHECK_D;
    #endif
  #endif

  
  for (int rowIndex=0; rowIndex < rowCount; rowIndex++) {
    // iterate the columns
    byte curRow = rows[rowIndex];
    if (anyKeyPressed) {
      pinMode(curRow, INPUT_PULLUP);
    }
    
    for (int colIndex=0; colIndex < colCount; colIndex++) {
      // col: set to output to low
      byte curCol = cols[colIndex];
      if (anyKeyPressed) {
        #ifdef FASTCOLS
          FASTCOLS_PINCONFIG = FASTCOLS_PINCONFIG | (1 << curCol);
          FASTCOLS_PORT = FASTCOLS_PORT & !(1 << curCol);
        #else
          pinMode(curCol, OUTPUT);
          digitalWrite(curCol, LOW);
        #endif
      }

      if (debounceMs[colIndex][rowIndex]>0) { // If debouncing is still active for this key, ignore all input
        if (debounceMs[colIndex][rowIndex] >= debouceMsSinceLast) {
          debounceMs[colIndex][rowIndex] -= debouceMsSinceLast;
        } else {
          debounceMs[colIndex][rowIndex] = 0;
        }
        changedValue[colIndex][rowIndex] = false;
      } else { // If debouncing is not active, process the key press
        bool buttonPressed = (anyKeyPressed) && (digitalRead(curRow) == LOW);
        
        keys[colIndex][rowIndex] = buttonPressed;
        if ((lastValue[colIndex][rowIndex] != buttonPressed)) {
          changedValue[colIndex][rowIndex] = true;
          debounceMs[colIndex][rowIndex] = DEBOUNCE_MS;
          anyKeyReleased = anyKeyReleased | buttonPressed;
          anyKeyChanged = true;
        } else {
          changedValue[colIndex][rowIndex] = false;
        }
  
        lastValue[colIndex][rowIndex] = buttonPressed;
      }

      if (anyKeyPressed) {
        #ifdef FASTCOLS
          FASTCOLS_PINCONFIG = FASTCOLS_PINCONFIG & !(1 << curCol);
          FASTCOLS_PORT = FASTCOLS_PORT & !(1 << curCol);
        #else
          pinMode(curCol, INPUT);
        #endif
      }
    }
    if (anyKeyPressed) {
      pinMode(curRow, INPUT);
    }
  }

  #ifdef FASTROWCHECK_B
    DDRB &= ~FASTROWCHECK_B;
    PORTB |= FASTROWCHECK_B;
  #endif
  #ifdef FASTROWCHECK_C
    DDRC &= ~FASTROWCHECK_C;
    PORTC |= FASTROWCHECK_C;
  #endif
  #ifdef FASTROWCHECK_D
    DDRD &= ~FASTROWCHECK_D;
    PORTD |= FASTROWCHECK_D;
  #endif
  #ifdef FASTROWCHECK_E
    DDRE &= ~FASTROWCHECK_E;
    PORTE |= FASTROWCHECK_E;
  #endif
  #ifdef FASTROWCHECK_F
    DDRF &= ~FASTROWCHECK_F;
    PORTF |= FASTROWCHECK_F;
  #endif
  #ifdef FASTCOLCHECK_D
    DDRD &= ~FASTCOLCHECK_D;
    PORTD |= FASTCOLCHECK_D;
  #endif

  updateStickyKeyStates();
  rolloverStickyKeyStates();

  if (anyKeyReleased) {
    wakeEverythingUp();
  }
  return anyKeyChanged;
}

bool keyPressed(int colIndex, int rowIndex) {
  return changedValue[colIndex][rowIndex] && keys[colIndex][rowIndex] == true;
}

bool keyReleased(int colIndex, int rowIndex) {
  return changedValue[colIndex][rowIndex] && keys[colIndex][rowIndex] == false;
}

bool keyChanged(int colIndex, int rowIndex) {
  return changedValue[colIndex][rowIndex];
}

bool keyActive(int colIndex, int rowIndex) {
  return keys[colIndex][rowIndex] == true;
}

bool isPrintableKey(int colIndex, int rowIndex) {
  return keyboard_symbol[colIndex][rowIndex] != NULL || keyboard[colIndex][rowIndex] != NULL;
}

void changeKeyboardBacklight(int change1, int change2, bool on) {
  setKeyboardBacklight(keyboardLight1 + change1, keyboardLight2 + change2, on);
}

void setKeyboardBacklight(int pwmValue1, int pwmValue2, bool on) {
  if (pwmValue1 > 255) {
    pwmValue1 = 255;
  }
  if (pwmValue1 < 0) {
    pwmValue1 = 0;
  }
  if (pwmValue2 > 255) {
    pwmValue2 = 255;
  }
  if (pwmValue2 < 0) {
    pwmValue2 = 0;
  }
  keyboardLight1 = pwmValue1;
  keyboardLight2 = pwmValue2;
  if (on) {
    #ifdef KEYBOARD_LIGHT_PIN_1
      analogWrite(KEYBOARD_LIGHT_PIN_1, keyboardLight1);
    #endif
    #ifdef KEYBOARD_LIGHT_PIN_2
      analogWrite(KEYBOARD_LIGHT_PIN_2, keyboardLight2);
    #endif
  } else {
    #ifdef KEYBOARD_LIGHT_PIN_1
      analogWrite(KEYBOARD_LIGHT_PIN_1, 0);
    #endif
    #ifdef KEYBOARD_LIGHT_PIN_2
      analogWrite(KEYBOARD_LIGHT_PIN_2, 0);
    #endif
  }
}

void unstickKeys() {
  if (anyKeyReleased) {
    stickySym = (stickySym==STICKY_STATUS_STICKY) ? keyPressed(K_SYM) : stickySym;
    stickyLsh = (stickyLsh==STICKY_STATUS_STICKY) ? keyPressed(K_LSH) : stickyLsh;
    stickyRsh = (stickyRsh==STICKY_STATUS_STICKY) ? keyPressed(K_RSH) : stickyRsh;
    stickyCtrl= (stickyCtrl==STICKY_STATUS_STICKY)? keyPressed(K_MIC) : stickyCtrl;
    stickyAlt = (stickyAlt==STICKY_STATUS_STICKY) ? keyPressed(K_ALT) : stickyAlt;
  }
}

void resetStickyKeys() {
  stickySym = STICKY_STATUS_OPEN;
  stickyLsh = STICKY_STATUS_OPEN;
  stickyRsh = STICKY_STATUS_OPEN;
  stickyCtrl= STICKY_STATUS_OPEN;
  stickyAlt = STICKY_STATUS_OPEN;
}
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
void loop() {
  idleWakeup = false;
  unsigned long startms = millis();
  #if BOARD_TYPE == ESP32 || BOARD_TYPE == FAIRBERRY_ESP32S3_SMART
  if (bleKeyboard.isConnected()) {
  #endif
    if (readMatrix(startms-lastDebounceMs)) { // some key changed
      printMatrix();
      unstickKeys();

      // increase backlight if mic key + sym key is pressed
      if (keyActive(K_MIC) && keyPressed(K_SYM)) {
        changeKeyboardBacklight(keyboardLightSteps, keyboardLightSteps, true);
      }
      // decrease backlight if mic key + right shift key is pressed
      if (keyActive(K_MIC) && keyPressed(K_RSH)) {
        changeKeyboardBacklight(-keyboardLightSteps, -keyboardLightSteps, true);
      }

      // instant powersave mode if SYM + Enter is pressed
      if (keyActive(K_SYM) && keyPressed(K_ENTER)) {
        idleTimeout = 0;
      }

      if ((keyPressed(K_LSH) && keyActive(K_RSH)) || (keyActive(K_LSH) && keyPressed(K_RSH))) {
        cursorMode = !cursorMode;
        resetStickyKeys();
      }

      #if defined(AUDIO_ENABLED) && BOARD_TYPE == FAIRBERRY_ESP32S3_SMART
        // SYM + Backspace: toggle voice recording start/stop.
        if (keyActive(K_SYM) && keyPressed(K_BACKSPACE)) {
          if (audioRecordingActive) {
            audioStopRecording();
            audioPlayTone(1200, 120);
          } else {
            String path = storageNextRecordingPath();
            if (path.length() > 0 && audioStartRecording(path)) {
              audioPlayTone(1800, 120);
            } else {
              audioPlayTone(400, 200); // low beep: couldn't start (e.g. voice typing is already recording)
            }
          }
        }
      #endif

      #if defined(TRANSFER_MODE_ENABLED) && BOARD_TYPE == FAIRBERRY_ESP32S3_SMART
        // SYM + T: toggle transfer mode (local web dashboard). Types the
        // URL as keystrokes into the host on activation -- focus a text
        // field first if you want to actually capture it.
        if (keyActive(K_SYM) && keyPressed(K_T)) {
          transferModeToggle();
        }
      #endif

      #if defined(VOICE_TYPING_ENABLED) && BOARD_TYPE == FAIRBERRY_ESP32S3_SMART
        // SYM + V: start/stop voice typing. Stopping runs the whole
        // transcribe -> read-back -> confirm flow before returning (see
        // voice_typing.h's file header for why this blocks).
        if (keyActive(K_SYM) && keyPressed(K_V)) {
          voiceTypingToggle();
        }
      #endif
    }
    lastDebounceMs = startms;
    #ifdef SERIAL_DEBUG_LOG
      Serial.print("matrix: ");
      Serial.println(millis()-startms);
    #endif
    #ifdef TRACKBALL_ENABLED
      trackballPoll();
    #endif
  #if BOARD_TYPE == ESP32 || BOARD_TYPE == FAIRBERRY_ESP32S3_SMART
  }
  #endif

  #if defined(AUDIO_ENABLED) && BOARD_TYPE == FAIRBERRY_ESP32S3_SMART
    // Runs regardless of BLE connection state -- recording a voice note
    // shouldn't require an active host connection.
    audioRecordChunk();
  #endif
  #if defined(WIFI_TRANSCRIPTION_ENABLED) && BOARD_TYPE == FAIRBERRY_ESP32S3_SMART
    whisperPoll();
  #endif
  #if defined(TRANSFER_MODE_ENABLED) && BOARD_TYPE == FAIRBERRY_ESP32S3_SMART
    transferModePoll();
  #endif

  #ifdef BLINK_IN_CURSOR_MODE
    if (idleTimeout>=millis()) {
      if (cursorMode && blinkTimeout<millis()) {
        blinkTimeout = millis() + BLINK_TIMEOUT;
        blinkState = !blinkState;
      } else if (!cursorMode) {
        blinkState = true;
      }
      changeKeyboardBacklight(0, 0, blinkState);
    }
  #endif
  #ifdef LED0_IN_CURSOR_MODE
    digitalWrite(LED0_PIN, cursorMode);
  #endif

  if (idleTimeout<millis()) {
    #ifdef SERIAL_DEBUG_LOG
      Serial.println("Sleep");
    #endif
    changeKeyboardBacklight(0, 0, false);
    resetStickyKeys();
    firstSleep = false;
    #ifdef POWERSAVE_ARDUINO_POWERDOWN
      if (!connectionNeedsReinit) {
        Keyboard.end();
        USBDevice.detach();
        USBCON &= ~(1 << USBE);
        //USBCON |= (1 << FRZCLK);
        
        //USBDevice.standby();

        delay(300);
        while (USBDevice.isSuspended()) {}
        USBCON |= (1 << USBE);
        USBDevice.attach();
        connectionNeedsReinit = true;
      }
      LowPower.powerDown(SLEEP_15MS, ADC_OFF, BOD_OFF);
    #endif
    #ifdef POWERSAVE_ARDUINO_CLOCKDOWN
      CLKPR = 0b10000000;
      CLKPR = ARDUINO_CLOCKDOWN_DIVISION_VALUE;
      CLKPR = ARDUINO_CLOCKDOWN_DIVISION_VALUE;
      CLKPR = ARDUINO_CLOCKDOWN_DIVISION_VALUE;
      isClockedDown = true;
    #endif
    #ifdef POWERSAVE_ARDUINO_IDLE
      power_twi_disable();
      power_adc_disable();
      power_spi_disable();
      power_usart0_disable();
      power_usart1_disable();
      if (!connectionNeedsReinit) {
        Keyboard.end();
        USBDevice.detach();
        USBCON &= ~(1 << USBE);

        delay(300);
        while (USBDevice.isSuspended()) {}
        USBCON |= (1 << USBE);
        USBDevice.attach();
        connectionNeedsReinit = true;
      }
      LowPower.idle(SLEEP_120MS, ADC_OFF, TIMER4_OFF, TIMER3_OFF, TIMER1_OFF, TIMER0_OFF, SPI_OFF, USART1_OFF, TWI_OFF, USB_ON);
    #endif
    #ifdef POWERSAVE_ESP32_LIGHT_SLEEP
      if (!connectionNeedsReinit) {
        btStop();
        connectionNeedsReinit = true;
      }
      esp_sleep_enable_timer_wakeup(SLEEP_DURATION);
      esp_light_sleep_start();
    #endif
  }
  #ifdef POWERSAVE_ARDUINO_IDLE_DURING_ACTIVE
    if (!firstSleep) {
      LowPower.idle(SLEEP_120MS, ADC_OFF, TIMER4_OFF, TIMER3_OFF, TIMER1_OFF, TIMER0_OFF, SPI_OFF, USART1_OFF, TWI_OFF, USB_ON);
    }
  #endif
  #ifdef SERIAL_DEBUG_LOG
    Serial.print("total:  ");
    Serial.println(millis()-startms);
  #endif
}

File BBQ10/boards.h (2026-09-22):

#if BOARD_TYPE == FAIRBERRY_V0_1_1 || BOARD_TYPE == FAIRBERRY_V0_2_0 || BOARD_TYPE == FAIRBERRY_V0_3_0 || BOARD_TYPE == ARDUINO || BOARD_TYPE==BEETLE
  #define CHIP_TYPE CHIP_ATMEGA32U4
#elif BOARD_TYPE == ESP32 || BOARD_TYPE == FAIRBERRY_ESP32S3_SMART
  #define CHIP_ESP32
#else
  #error "No valid BOARD_TYPE selected. Needs to be any of FAIRBERRY_V0_1_1, FAIRBERRY_V0_2_0, FAIRBERRY_V0_3_0, ARDUINO, BEETLE, ESP32, FAIRBERRY_ESP32S3_SMART"
#endif

#if defined(POWERSAVE_ARDUINO_IDLE) && defined(POWERSAVE_ARDUINO_POWERDOWN)
  #error "Cannot have POWERSAVE_ARDUINO_IDLE and POWERSAVE_ARDUINO_POWERDOWN at the same time!"
#endif

#if CHIP_TYPE != CHIP_ATMEGA32U4 && defined(POWERSAVE_ARDUINO_IDLE)
  #error "Only boards with ATMEGA32U4 chips suport POWERSAVE_ARDUINO_IDLE!"
#endif

#if CHIP_TYPE != CHIP_ATMEGA32U4 && defined(POWERSAVE_ARDUINO_POWERDOWN)
  #error "Only boards with ATMEGA32U4 chips suport POWERSAVE_ARDUINO_POWERDOWN!"
#endif

#if defined(POWERSAVE_ARDUINO_CLOCKDOWN) && !defined(ARDUINO_CLOCKDOWN_DIVISION)
  #error "ARDUINO_CLOCKDOWN_DIVISION needs to be set (to 1,2,4,8,16,32,64,128 or 256) if POWERSAVE_ARDUINO_CLOCKDOWN is enabled"
#endif

#ifdef ARDUINO_CLOCKDOWN_DIVISION
  #define ARDUINO_CLOCKDOWN_RESET_VALUE 0b00000000
  #if ARDUINO_CLOCKDOWN_DIVISION == 1
    #define ARDUINO_CLOCKDOWN_DIVISION_VALUE 0b00000000
  #elif ARDUINO_CLOCKDOWN_DIVISION == 2
    #define ARDUINO_CLOCKDOWN_DIVISION_VALUE 0b00000001
  #elif ARDUINO_CLOCKDOWN_DIVISION == 4
    #define ARDUINO_CLOCKDOWN_DIVISION_VALUE 0b00000010
  #elif ARDUINO_CLOCKDOWN_DIVISION == 8
    #define ARDUINO_CLOCKDOWN_DIVISION_VALUE 0b00000011
  #elif ARDUINO_CLOCKDOWN_DIVISION == 16
    #define ARDUINO_CLOCKDOWN_DIVISION_VALUE 0b00000100
  #elif ARDUINO_CLOCKDOWN_DIVISION == 32
    #define ARDUINO_CLOCKDOWN_DIVISION_VALUE 0b00000101
  #elif ARDUINO_CLOCKDOWN_DIVISION == 64
    #define ARDUINO_CLOCKDOWN_DIVISION_VALUE 0b00000110
  #elif ARDUINO_CLOCKDOWN_DIVISION == 128
    #define ARDUINO_CLOCKDOWN_DIVISION_VALUE 0b00000111
  #elif ARDUINO_CLOCKDOWN_DIVISION == 256
    #define ARDUINO_CLOCKDOWN_DIVISION_VALUE 0b00001000
  #endif
#endif

#if BOARD_TYPE == FAIRBERRY_V0_1_1 || BOARD_TYPE == FAIRBERRY_V0_2_0 || BOARD_TYPE == FAIRBERRY_V0_3_0
  #define F_CPU 16000000
  #define TX_RX_LED_INIT  DDRE |= (1<<6), DDRB |= (1<<0)
  #define TXLED0      PORTE |= (1<<6)
  #define TXLED1      PORTE &= ~(1<<6)
  #define RXLED0      PORTB |= (1<<0)
  #define RXLED1      PORTB &= ~(1<<0)
#endif

#if CHIP_TYPE == CHIP_ATMEGA32U4
  #if !defined(DEBUG_SERIAL_INSTEAD_OF_USB)
    #include "Keyboard.h"
  #endif
  #include "LowPower.h"
  #include <avr/power.h>

  #ifdef DEBUG_SERIAL_INSTEAD_OF_USB
    #define KEYBOARD_BEGIN(layout) Serial.begin()
    #define KEYBOARD_BEGIN(layout) ;
    #define KEYBOARD_PRESS(key) Serial.print("Pressed ");Serial.println(key);
    #define KEYBOARD_RELEASE(key) Serial.print("Released ");Serial.println(key);
  #else
    #define KEYBOARD_BEGIN(layout) Keyboard.begin(layout)
    #define KEYBOARD_END() Keyboard.end()
    #define KEYBOARD_PRESS(key) Keyboard.press(key)
    #define KEYBOARD_RELEASE(key) Keyboard.release(key)
  #endif
#elif BOARD_TYPE == ESP32 || BOARD_TYPE == FAIRBERRY_ESP32S3_SMART
  #include "analogWrite.h"
  #define USE_NIMBLE
  #include <BleKeyboard.h>
  #include "esp_bt.h"
  #include "esp_pm.h"
  #include "esp_wifi.h"
  BleKeyboard bleKeyboard;

  #define SLEEP_DURATION 120000L
  #define KEYBOARD_BEGIN(layout) bleKeyboard.begin()
  #define KEYBOARD_END() bleKeyboard.end()
  #define KEYBOARD_PRESS(key) bleKeyboard.press(key)
  #define KEYBOARD_RELEASE(key) bleKeyboard.release(key)
#endif
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

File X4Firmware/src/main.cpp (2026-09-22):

// Fairberry Writer Deck -- X4 firmware
//
// A distraction-free writer app for the Xteink X4, built on FreeInk SDK,
// driven by the Fairberry keyboard over BLE HID (see ../BBQ10 for the
// keyboard side, and Documentation/Hardware_X4_Writer_Deck.md for the
// full picture of how the two halves fit together).
//
// CONFIDENCE NOTE: I built this against FreeInk SDK's documented API
// (freeink.org/docs) without a compiler or the actual SDK headers in
// front of me -- I could read the docs site but not browse the real
// source tree. The overall shape (BoardConfig/SdMan/EInkDisplay/BleHid
// init in setup(), a textArea-based editor screen, autosave to SD) is
// solidly grounded in what the docs describe. The exact field/method
// names marked "VERIFY:" below are my best reconstruction from prose
// descriptions of the API, not confirmed against a header file -- check
// these against your actual freeink-sdk checkout before this will
// compile, let alone run correctly.

#include <Arduino.h>
#include <FreeInkDisplay.h>   // VERIFY: actual header name/path in your checkout
#include <BoardConfig.h>
#include <SDCardManager.h>
#include <BleKeyboardHost.h>  // VERIFY: header name -- docs refer to the class as BleKeyboardHost, accessed via a `BleHid` global
#include <FreeInkUI.h>

// ---- Document state ----
// In-RAM buffer. Fine for a "few thousand words at a time" writer-deck
// document; a full-book-length single document would want a
// chunked/streaming buffer instead -- not attempted here, this is scoped
// to short-form distraction-free writing, not a general text editor.
String documentText = "";
size_t caretPos = 0;
String currentFilename = "";
unsigned long lastEditMs = 0;
unsigned long lastAutosaveMs = 0;
int editsSinceFullRefresh = 0;

#define AUTOSAVE_INTERVAL_MS 5000
#define FULL_REFRESH_EVERY_N_EDITS 40 // Periodic full refresh to clear e-ink ghosting from repeated fast partial updates

enum AppScreen { SCREEN_LIBRARY, SCREEN_EDITOR };
AppScreen currentScreen = SCREEN_LIBRARY;
AppScreen lastRenderedScreen = SCREEN_EDITOR; // deliberately != currentScreen so the first loop() renders once
bool screenDirty = true;

EInkDisplay display; // VERIFY: constructor likely wants a board profile/SPI pin set -- see lib-display docs

// Forward declarations -- unlike a .ino sketch, plain .cpp files here
// don't get Arduino's automatic function-prototype generation, so
// anything used before its definition needs one.
int wordCount();

// ---- SD helpers ----

String nextDraftPath() {
  for (int i = 0; i < 100000; i++) {
    char path[32];
    snprintf(path, sizeof(path), "/documents/DRAFT%05d.txt", i);
    if (!SdMan.exists(path)) { // VERIFY: SDCardManager's exists() call
      return String(path);
    }
  }
  return "";
}

void saveCurrentDocument() {
  if (currentFilename.length() == 0) return;
  File f = SdMan.open(currentFilename, FILE_WRITE); // VERIFY: SDCardManager's open() signature
  if (!f) return;
  f.print(documentText);
  f.close();
  lastAutosaveMs = millis();
}

// ---- Editor screen ----
// VERIFY: FreeInkApp's actual screen-function signature and the exact
// textArea()/statusBar() builder method parameter lists -- reconstructed
// from lib-ui's prose description ("the app owns the text buffer and
// caret offset; it word-wraps, draws the window of lines from topLine,
// and an optional caret") rather than a header.
ActionEvent editorScreen(ScreenBuilder &s) {
  s.statusBar(currentFilename.length() ? currentFilename : "(unsaved draft)",
              String(wordCount()) + " words");
  s.textArea(documentText, caretPos);
  return s.finish();
}

int wordCount() {
  int count = 0;
  bool inWord = false;
  for (size_t i = 0; i < documentText.length(); i++) {
    bool isSpace = isspace(documentText[i]);
    if (!isSpace && !inWord) count++;
    inWord = !isSpace;
  }
  return count;
}

// ---- Library screen ----
ActionEvent libraryScreen(ScreenBuilder &s) {
  s.header("Fairberry Writer Deck");
  // VERIFY: list()'s actual data-source signature -- this assumes it can
  // take a directory path and a selection callback, per lib-ui's "list --
  // virtualized rows with section headings" description, but the real
  // parameter shape wasn't confirmed.
  s.list("/documents", [](const String &path) {
    currentFilename = path;
    File f = SdMan.open(path, FILE_READ);
    if (f) {
      documentText = f.readString();
      f.close();
      caretPos = documentText.length();
    }
    currentScreen = SCREEN_EDITOR;
  });
  s.button("+ New draft", []() {
    currentFilename = nextDraftPath();
    documentText = "";
    caretPos = 0;
    currentScreen = SCREEN_EDITOR;
  });
  return s.finish();
}

// ---- Keyboard input handling ----
// VERIFY: KeyEvent's exact field names and SpecialKey enum members --
// lib-ble's docs describe "ev.special is a SpecialKey (PageDown,
// arrows…); ev.ch is printable input" but I don't have the full
// SpecialKey enum (does it include Enter/Backspace/Escape, or do those
// arrive as ev.ch with the usual ASCII control codes \n / \b / 0x1B?).
// Written here assuming the ASCII-control-code path since that's the
// more common HID-to-app convention and needs no extra enum members --
// swap to ev.special checks if your checkout's SpecialKey enum actually
// carries these.
void handleKeyEvent(const KeyEvent &ev) {
  lastEditMs = millis();
  editsSinceFullRefresh++;

  if (ev.special == SpecialKey::ArrowLeft) {
    if (caretPos > 0) caretPos--;
    return;
  }
  if (ev.special == SpecialKey::ArrowRight) {
    if (caretPos < documentText.length()) caretPos++;
    return;
  }
  // ArrowUp/ArrowDown for line navigation intentionally not implemented
  // yet -- needs textArea to expose which column/line the caret is on,
  // which wasn't in the docs I could read. Left/right + word-wrap
  // scrolling covers basic editing in the meantime.

  if (ev.ch == '\b' || ev.ch == 0x7F) {
    if (caretPos > 0) {
      documentText.remove(caretPos - 1, 1);
      caretPos--;
    }
    return;
  }
  if (ev.ch == 0x1B) { // Escape: back to library (with an autosave first)
    saveCurrentDocument();
    currentScreen = SCREEN_LIBRARY;
    return;
  }
  if (ev.ch == '\n' || ev.ch == '\r' || ev.ch >= 0x20) {
    char c = (ev.ch == '\r') ? '\n' : ev.ch;
    documentText = documentText.substring(0, caretPos) + c + documentText.substring(caretPos);
    caretPos++;
  }
}

void setup() {
  BoardConfig::holdPowerRails();
  BoardConfig::releaseSdRail();
  SdMan.begin();
  if (!SdMan.exists("/documents")) {
    SdMan.mkdir("/documents"); // VERIFY: SDCardManager's mkdir() call
  }

  display.begin();
  display.clearScreen();

  BleHid.begin("Fairberry Writer Deck");
}
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

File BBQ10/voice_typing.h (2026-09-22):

// Interactive voice typing: record -> transcribe (Whisper) -> read the
// transcript back (TTS) so you can verify it heard you right -> confirm
// (Enter) to type it into the host, or discard (Backspace) and try again.
//
// This is a separate mode from the async batch Whisper sync in
// whisper_sync.h -- that one is for longer recordings you don't want to
// wait on; this one is for short dictated text you want to send right
// now, like a phone's voice-to-text keyboard.
//
// Toggle recording with SYM + V (press once to start, again to stop).
// Stopping triggers the transcribe+readback+confirm flow immediately.
//
// HONEST LIMITATION: this whole flow (WiFi connect + Whisper upload +
// TTS request + playback + waiting for your confirm keypress) runs
// blocking/synchronous -- the keyboard and trackball don't respond to
// anything else while it's in progress. Making this properly
// non-blocking would need a real async state machine across multiple
// network round-trips, which is meaningfully more firmware complexity
// than this pass attempts. Expect a real, noticeable pause (WiFi
// connect alone can take several seconds, plus two API round-trips)
// between stopping the recording and hearing it read back.

#if defined(VOICE_TYPING_ENABLED) && BOARD_TYPE == FAIRBERRY_ESP32S3_SMART

#define VOICE_TYPING_TEMP_PATH "/recordings/_voice_typing_tmp.wav"
#ifndef VOICE_TYPING_CONFIRM_TIMEOUT_MS
  #define VOICE_TYPING_CONFIRM_TIMEOUT_MS 15000 // Auto-discard if no confirm/discard keypress in time
#endif
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

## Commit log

2026-09-22 Retarget project scope: e-ink / Free Ink SDK devices (Xteink X4)
    Reframes this fork around attaching the BBQ10 keyboard to e-ink readers
    running the Free Ink SDK, starting with the Xteink X4, instead of phones.
    - README: new project goal, and an honest status section noting that
    generic keyboard-HID host support isn't confirmed to exist yet in
    Free Ink SDK (BLE HID Central there is currently scoped to
    page-turner remotes; no documented USB HID host support either).
    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
    [Fairberry.scad, XteinkX4.scad, configuration.h]
2026-09-22 Correct BLE HID host claims after reading the actual lib-ble docs
    The freeink.org/docs/lib-ble page is a client-rendered SPA that didn't
    come through on a plain fetch; rendering it properly showed the earlier
    docs were wrong on this point. FreeInk SDK's BleKeyboardHost (lib-ble)
    is a real, general-purpose BLE HID host explicitly built for external
    keyboards (not just page-turner remotes as previously written here), and
    it works on ESP32-C3 as well as S3 -- so it covers the plain X4, not just
    the Classic/Pro.
    The actual open question is narrower than before: it's an opt-in
    FREEINK_CAP_BLE_HID_HOST build flag (off by default), so it comes down
    to whether the firmware actually flashed on a giv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
    [configuration.h]
2026-09-22 Add concrete build recipe for enabling BLE HID host on the X4
    Pulled the actual [env:xteink_x4] block from freeink-sdk's
    platformio.sample.ini to confirm it doesn't enable FREEINK_CAP_BLE_HID_HOST
    by default, and documented the exact build_flags/lib_deps addition needed
    so this is an actionable step instead of a vague "needs a custom build."
2026-09-22 Improve X4 case fit: use community-measured dimensions, point to real dummy model
    Found an actual to-scale Xteink X4 device model (Zorian22's Thingiverse
    thing:7287950, CC BY-NC-SA, companion to a case for the same device) with
    measured dimensions of 114.2 x 69.2 x 6.2mm, more accurate than the
    rounded 114 x 69 x 5.9mm spec-sheet numbers the preset used before.
    Updated the XteinkX4.scad preset's PHONE_WIDTH/PHONE_THICKNESS to match,
    and documented the path to a proper fit: download that dummy model
    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
    [XteinkX4.scad]
2026-09-22 Add ICSH044A BlackBerry trackball support for the ESP32 board type
    Wires a five-way trackball (ICSH044A / SparkFun BlackBerry Trackballer
    Breakout clone) alongside the BBQ10 keyboard matrix, opt-in via
    TRACKBALL_ENABLED. Movement is read as raw hall-sensor edges via
    interrupts (sources disagreed on the direction pins' idle polarity, so
    this counts transitions instead of assuming a signal shape) and
    synthesized into arrow-key taps; the center click sends Enter by default.
    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
    [configuration.h]
2026-09-22 Pivot to standalone battery-powered ESP32-S3 smart keyboard
    Drops the "no battery, host-powered" philosophy this project inherited
    from upstream: this adds a new BOARD_TYPE FAIRBERRY_ESP32S3_SMART for a
    standalone device that pairs wirelessly with the X4 (or any BLE HID
    host) instead of physically attaching to it. Keyboard + trackball stay
    the same firmware-side; new on top of that:
    - BBQ10/audio.h: I2S mic capture to WAV on SD, I2S speaker playback,
    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
    [configuration.h]
2026-09-22 Add local transfer-mode web dashboard (TRANSFER_MODE_ENABLED)
    Local-only alternative/complement to the Whisper cloud sync: SYM + T
    toggles a local web server (BBQ10/web_server.h, built on the ESP32 core's
    own WebServer.h, no extra library) for browsing and downloading
    recordings/transcripts over the LAN. No OpenAI account needed for this
    path, just WiFi credentials.
    Since this device has no screen, it can't display its own IP -- on
    activation it instead types the local URL as keystrokes into whatever's
    focused on the paired host, reusing the same BLE HID path as normal
    typing, rather than assuming a display that doesn't exist.
    Factored the WiFi connect/disconnect helpers out of whisper_syn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
    [configuration.h]
2026-09-22 Add voice typing: dictate, verify by ear via TTS, then send
    New mode (VOICE_TYPING_ENABLED, SYM + V) distinct from the existing
    batch Whisper sync: stop a short recording and it immediately uploads to
    Whisper, reads the transcript back through the speaker via the OpenAI
    TTS API so you can catch a bad transcription before it goes anywhere,
    then waits for Enter (types it into the host) or Backspace (discard).
    Closer to a phone's voice-to-text keyboard than to the note-recorder
    flow already in place.
    - BBQ10/tts.h: calls /v1/audio/speech, streams the response straight to
    the I2S speaker without buffering to SD, and parses the actual
    returned WAV header for sample rate rather than assuming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
    [configuration.h]
2026-09-22 Add X4 writer-deck firmware and restructure repo into four components
    Per request: keyboard firmware, X4 firmware, hardware, and web GUI as
    separate-but-interlinked pieces in one repo, rather than splitting the
    X4 side into the shelbeeely/freeink-sdk fork (attaching that repo to
    this session got auto-denied twice by the permission classifier, and
    the user preferred everything in one place anyway).
    New:
    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
2026-09-22 Add combined writer-deck case, reusing a real hinge from a reference model
    The user provided a reference case (XteinkX4FullCoverageFlipCase --
    BOTTOM/TOP/HINGE STLs, no embedded author/license metadata, confirm
    source license before public redistribution if it came from a site like
    Printables/MakerWorld). Analyzed its actual geometry (bounding boxes,
    triangle counts, point clustering by region) rather than guessing:
    - BOTTOM (27590 triangles) is the X4 cradle -- has real device-specific
    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
    [WriterDeck.scad, xteinkflipcaseBOTTOM.stl, xteinkflipcaseHINGE.stl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]
2026-09-22 Add verified KiCad schematic for ESP32-S3 smart keyboard mainboard
    Generate FairberryESP32S3Mainboard.kicad_sch programmatically from real
    KiCad symbol library data (ESP32-S3-WROOM-1, MCP73831 charger, MCP1700
    LDO, MAX98357A amp, ICS-43434 mic, MCP100 battery-low supervisor, plus a
    custom BBQ10KBD symbol built from the real Hirose connector pinout in
    KiCad/FairberryMainboard/library/Keyboard.lib). Pin assignments match
    BBQ10/boards.h's FAIRBERRY_ESP32S3_SMART board type exactly.
    Verified against kicad-cli: 30 components, 44 nets, every net has 2+
    pins and every pin is accounted for (no silent NCs). Fixed three bugs
    found along the way that made kicad-cli either segfault or silently
    drop eve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
    [FairberryESP32S3Mainboard.kicad_sch]
2026-09-22 Spec ESP32-S3-WROOM-1-N16R8 (octal PSRAM) and move mic I2S off GPIO35-37
    Settled the "which ESP32-S3 module" question by verifying real specs for
    several candidate boards (XIAO ESP32-S3, Unexpected Maker ProS3/FeatherS3,
    ESP32-S3-DevKitC-1) rather than guessing pin counts. None of the small
    integrated modules combine enough free GPIO for this design's ~28-pin
    budget with onboard USB-C+LiPo charging -- that combination doesn't
    really exist at this size class. Since this is a custom PCB, the better
    move is placing the bare ESP32-S3-WROOM-1 module directly (already done)
    and picking a specific SKU for the BOM rather than leaving flash/PSRAM
    unspecified.
    Picked -N16R8 (16MB flash, 8MB octal PSR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
    [FairberryESP32S3Mainboard.kicad_sch]
2026-09-22 Embed schematic SVG in the KiCad README and hardware doc
    Exported FairberryESP32S3Mainboard.svg from the current .kicad_sch
    (post mic-pin fix) via kicad-cli and committed it alongside the source
    schematic so it renders inline on GitHub, instead of only being
    reachable by opening the .kicad_sch file. Referenced from both the
    KiCad subfolder README and the main hardware doc's Pin plan section,
    with the regeneration command noted so it doesn't go stale after
    future schematic edits.
    Claude-Session: https://claude.ai/code/session_01APKxwwuAyE76aszQ6arZJ9
2026-09-22 Import the schematic netlist into a new .kicad_pcb
    kicad-cli 7's pcb subcommand only has export, not netlist import, and
    the GUI's "Update PCB from Schematic" dialog isn't scriptable, so this
    does that step directly against the pcbnew Python API
    (generator/build_pcb.py): load each component's real footprint, place
    it on an unrouted grid, and wire every pad to its net by pad number.
    Caught and fixed two real bugs this surfaced, both invisible at the
    schematic level since a Footprint property string is just text there,
    never validated against real files:
    - the microSD footprint reference (Connector_Card:Conn_01x08_MicroSD_Card)
    was a guessed name that doesn't exist; replaced with a real,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
    [FairberryESP32S3Mainboard.kicad_pcb, FairberryESP32S3Mainboard.kicad_sch]
